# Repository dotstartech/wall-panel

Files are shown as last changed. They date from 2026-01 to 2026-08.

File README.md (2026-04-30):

# Wall Panel

Wall Panel is a 4-inch wall-mounted touch display panel powered by Raspberry Pi Compute Module 4 (CM4). It features a 720x720 IPS multitouch display and can be used as a Home Assistant dashboard or any other embedded display application.

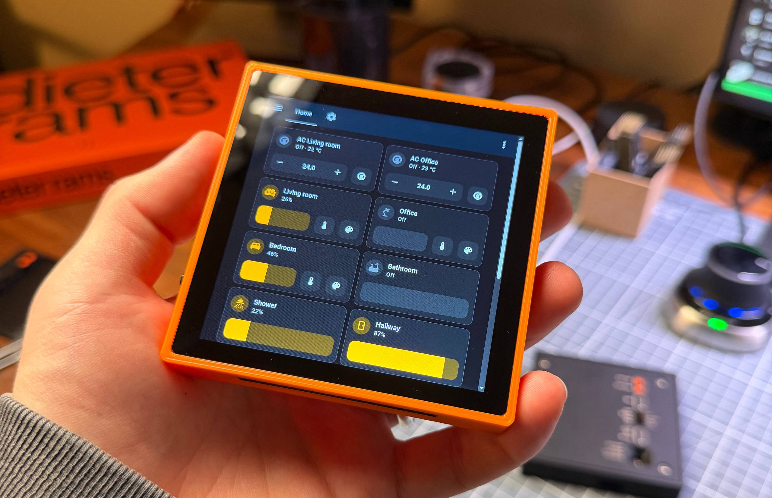
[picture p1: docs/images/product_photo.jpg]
Product photo


## Display
We use this [display](https://www.alibaba.com/product-detail/Square-4-Inch-IPS-LCD-Screen_1601268288719.html), but touch variant. It is 4 lane MIPI with i2c touch controller. 
- Display driver: ST7703
- Touch driver: FT6336U

## Possible use cases
- **Home Assistant Dashboard**. Perfect for wall-mounted smart home control panels with full touch interaction and high-resolution display.
- **Information Display**. Show weather, calendar, news, or any other dynamic content in your home or office.
- **Control Panel**. Use as a centralized control interface for IoT devices, lighting, or home automation systems.
- **Embedded Display**. Build custom applications using the full power of Raspberry Pi OS or any Linux distribution on the CM4.

## List of features
- **720x720 IPS Display** with multitouch support
- **Raspberry Pi Compute Module 4** as the main brain
- **External RTC** for accurate timekeeping
- **USB-C** for data and power
- **USB-OTG** support for device mode
- **Action Button** for user interaction
- **WiFi** connectivity
- **40-pin GPIO Header** for Raspberry Pi compatibility
- **SD Card** slot for storage expansion
- **Micro HDMI** output for external displays
- **EEPROM Flashing** capability for firmware updates
- **Backplane Connector** for power and data from the wall and future PoE backplate support

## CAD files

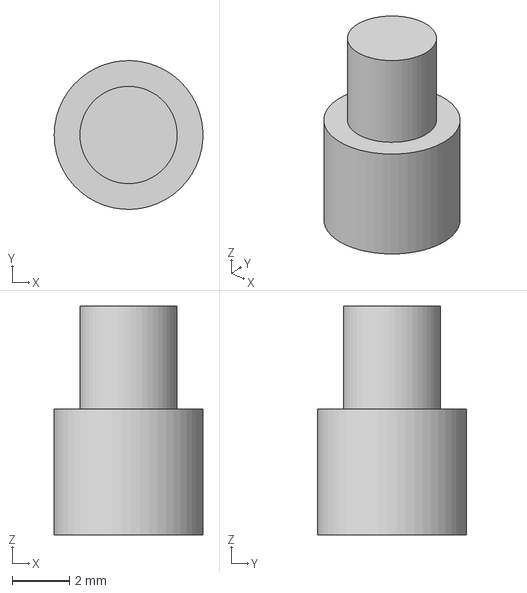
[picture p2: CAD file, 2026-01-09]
cad/wall-panel/back_button.step
5.20 x 5.20 x 8.00 mm

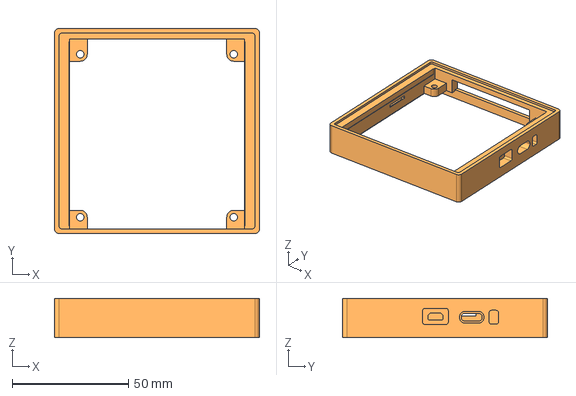
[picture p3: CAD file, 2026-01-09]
cad/wall-panel/frame.step
88.2 x 88.2 x 16.8 mm

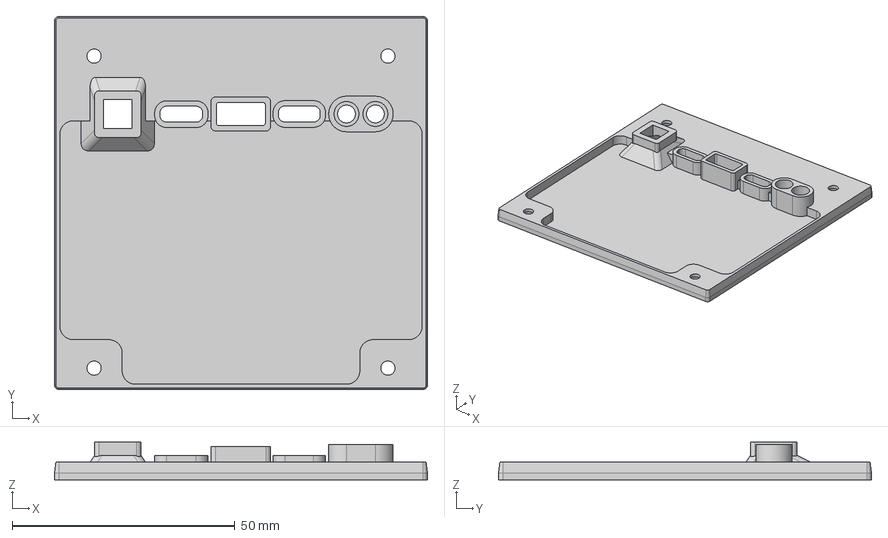
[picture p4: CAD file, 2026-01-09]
cad/wall-panel/back_lid.step
83.8 x 83.8 x 8.50 mm

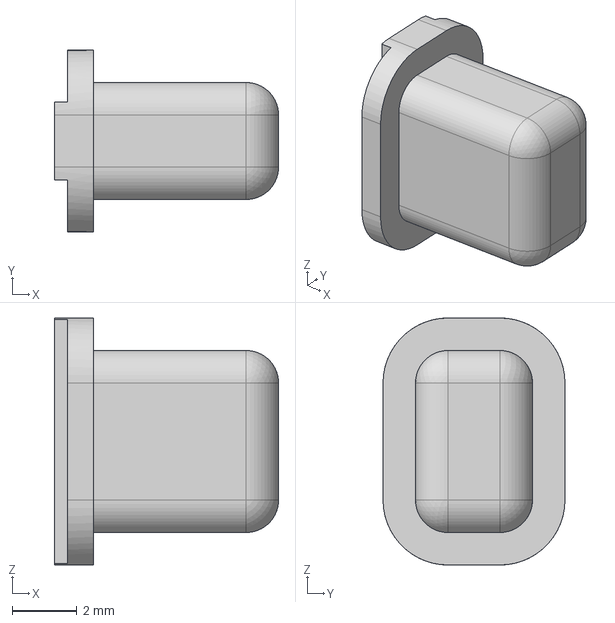
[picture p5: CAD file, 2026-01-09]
cad/wall-panel/side_button.step
6.90 x 5.60 x 7.60 mm

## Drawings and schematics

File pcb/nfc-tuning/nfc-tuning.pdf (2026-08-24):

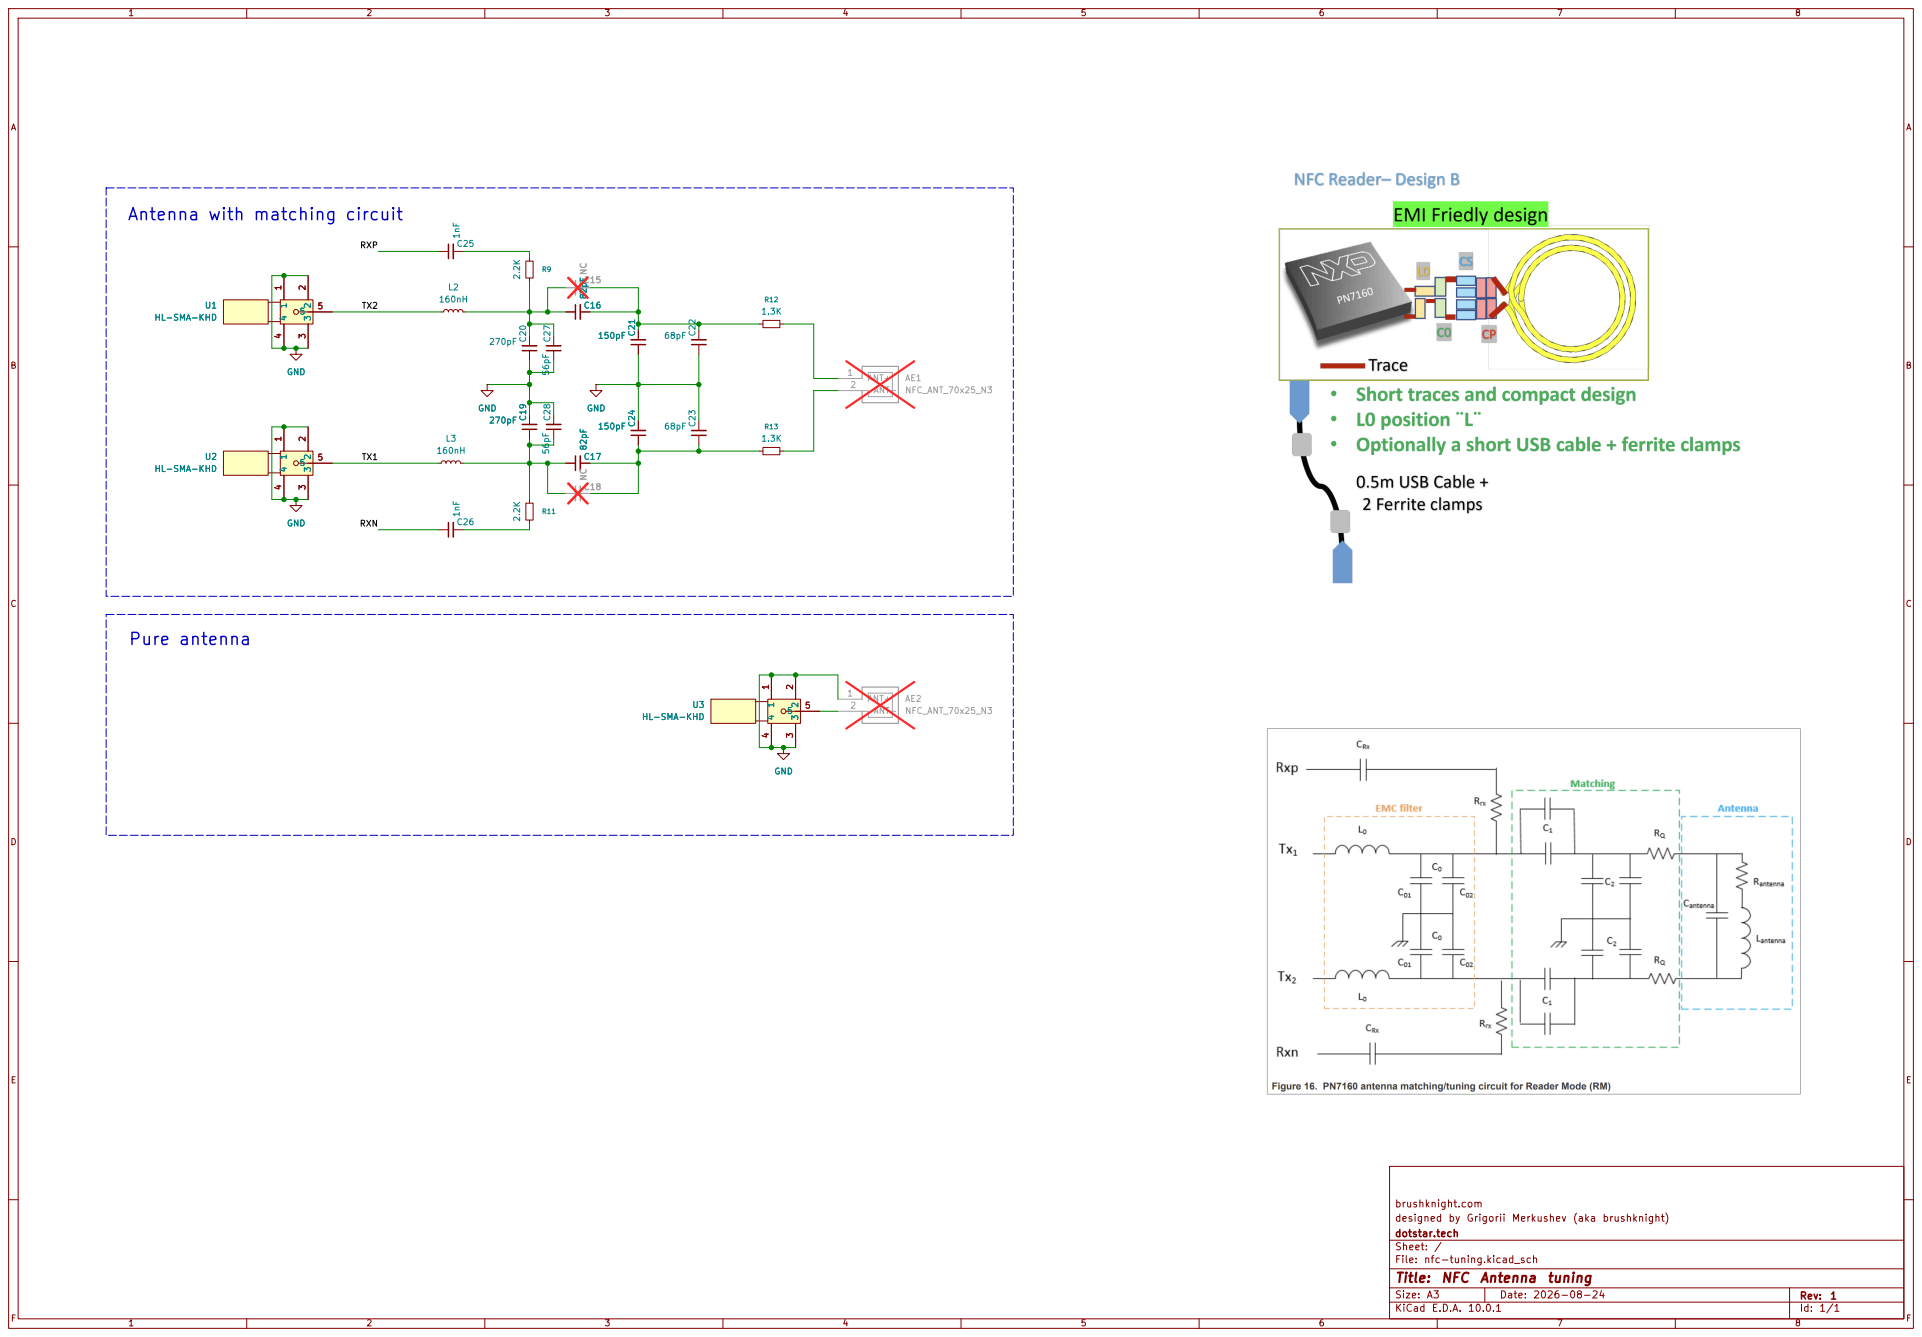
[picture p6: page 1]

Antenna with matching circuit

GND U1 HL-SMA-KHD

designed by Grigorii Merkushev (aka brushknight)
dotstar.tech
Sheet: /
File: nfc-tuning.kicad_sch
Title: NFC Antenna tuning

Size: A3 | Rev: 1 | F Date: 2026-08-24
KiCad E.D.A. 10.0.1 | Id: 1/1

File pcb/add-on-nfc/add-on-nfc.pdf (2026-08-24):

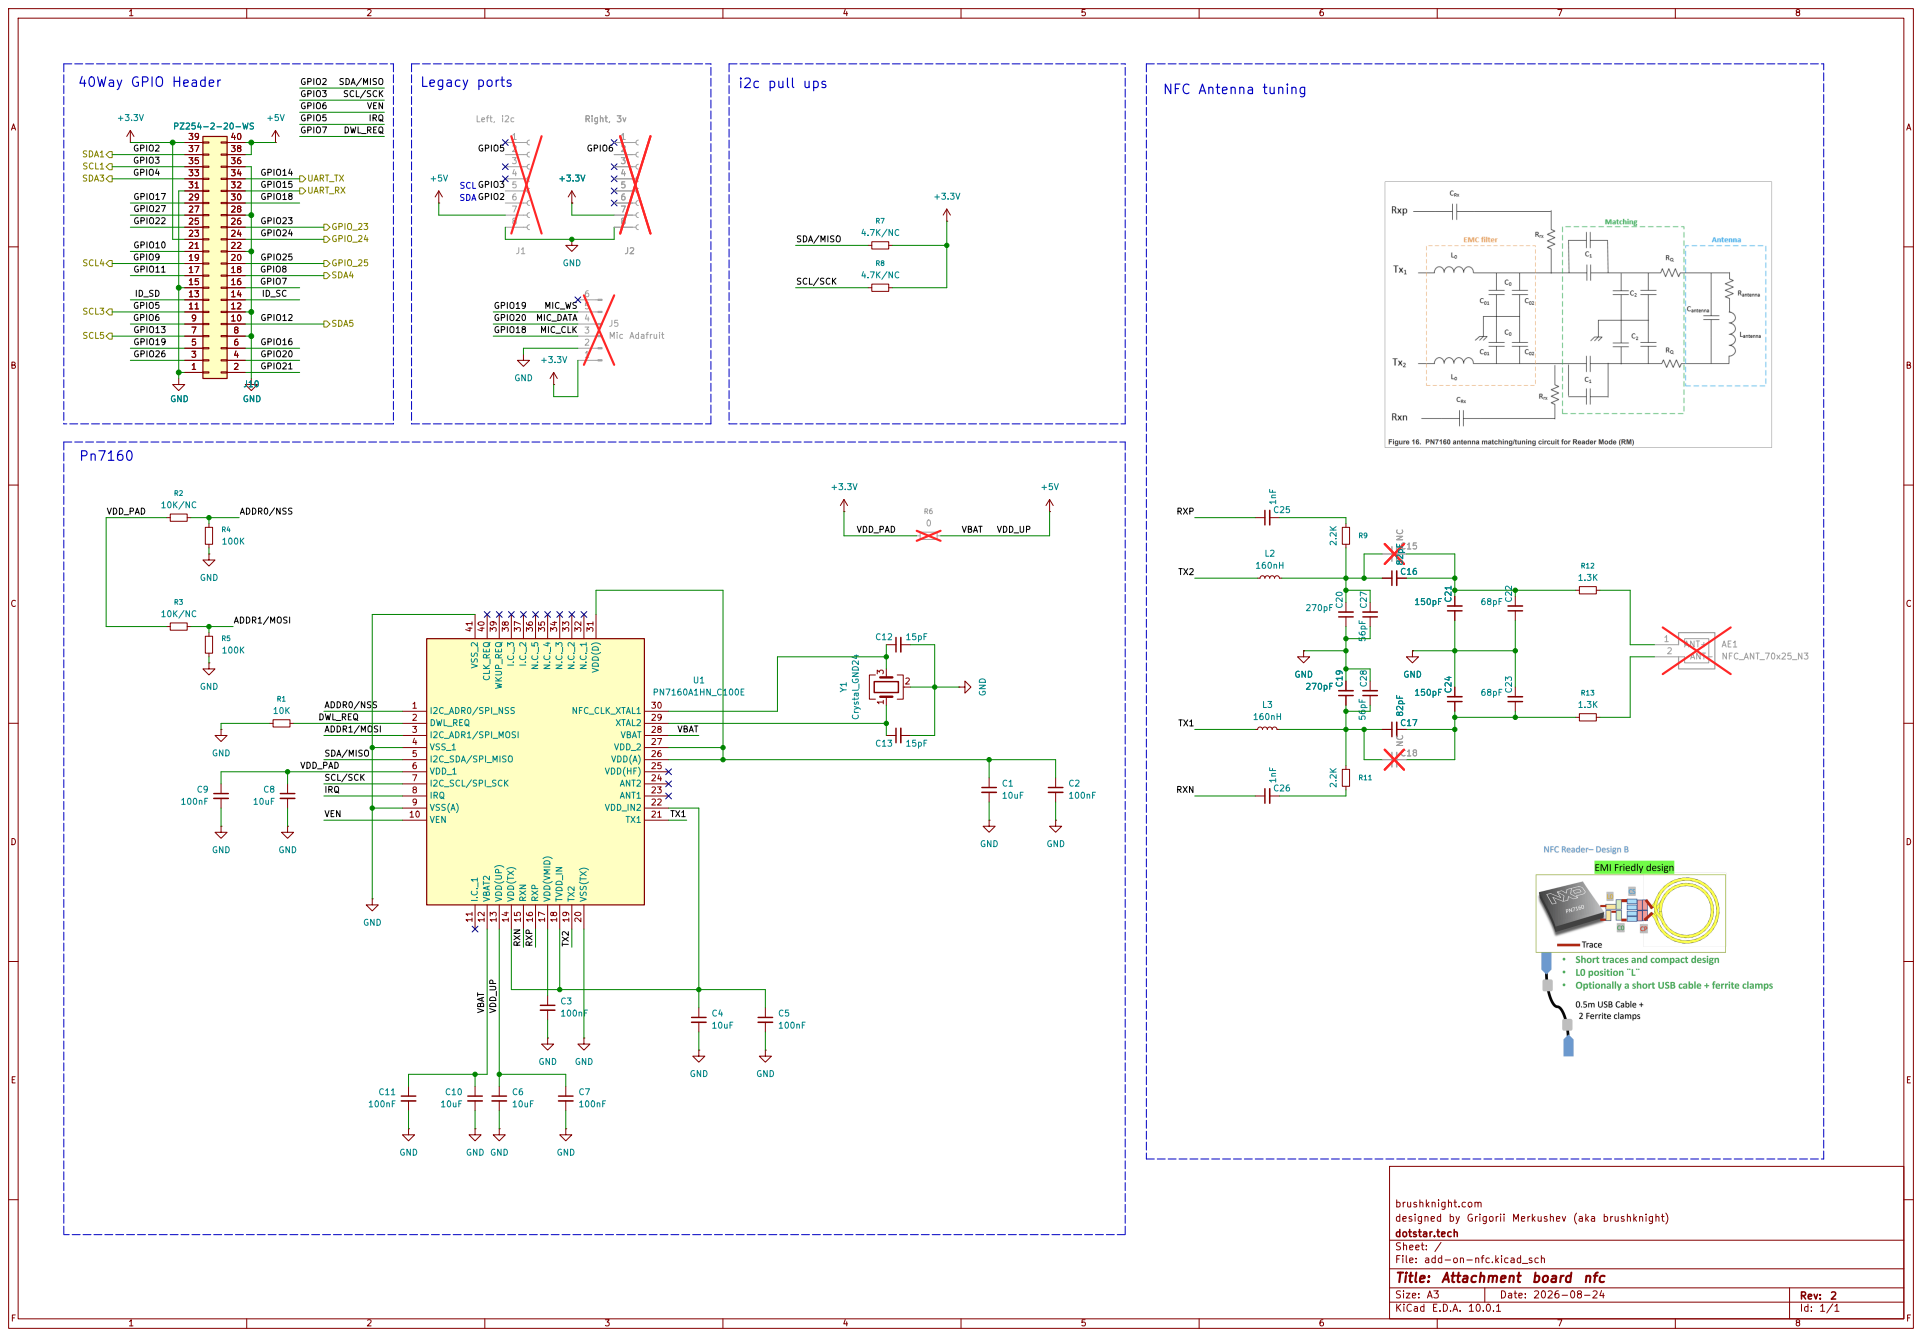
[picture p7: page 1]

brushknight.com
designed by Grigorii Merkushev (aka brushknight)
dotstar.tech
Sheet: /
File: add-on-nfc.kicad_sch
Title: Attachment board nfc

Size: A3 | Rev: 2 | F Date: 2026-08-24
KiCad E.D.A. 10.0.1 | Id: 1/1

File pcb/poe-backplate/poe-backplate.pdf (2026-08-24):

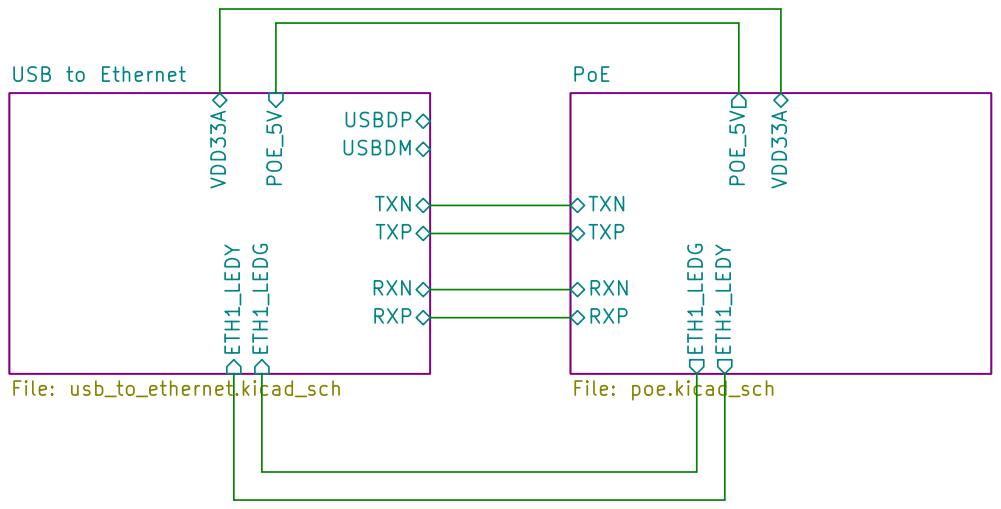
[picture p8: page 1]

brushknight.com
designed byGrigorii Merkushev (aka brushknight)
dotstar.tech
Sheet: /
File: poe-backplate.kicad_sch
Title: PoE Backplate

Size: A3 | Rev: 4 | F Date: 2026-08-05
KiCad E.D.A. 10.0.1 | Id: 1/3

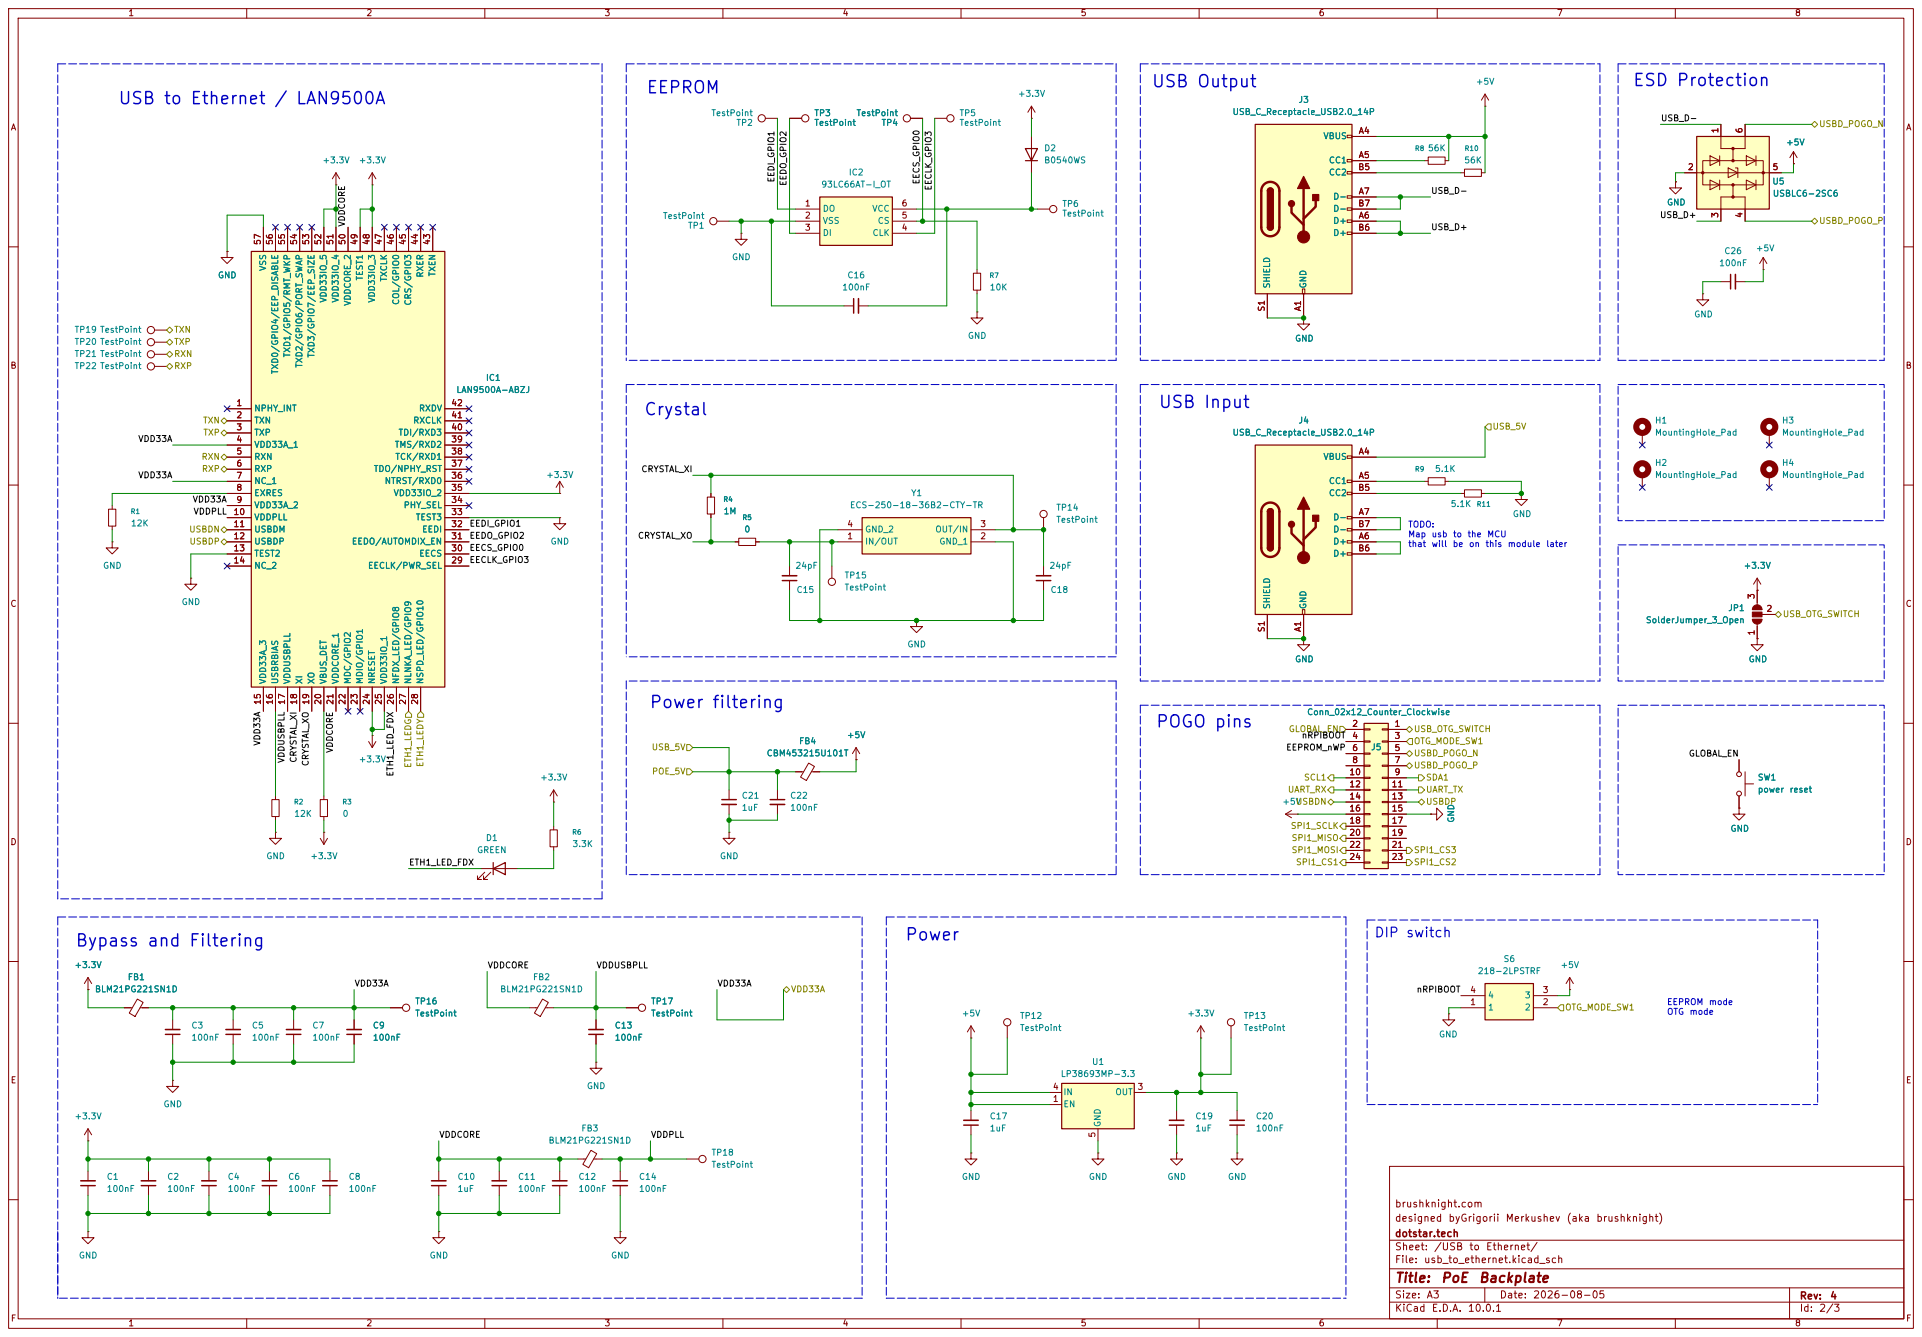
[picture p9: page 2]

USB Output USB to Ethernet / LAN9500A
TestPoint +3.3V

TODO: Map usb to the MCU

EEPROM mode OTG mode

brushknight.com
designed byGrigorii Merkushev (aka brushknight)
dotstar.tech
Sheet: /USB to Ethernet/
File: usb_to_ethernet.kicad_sch

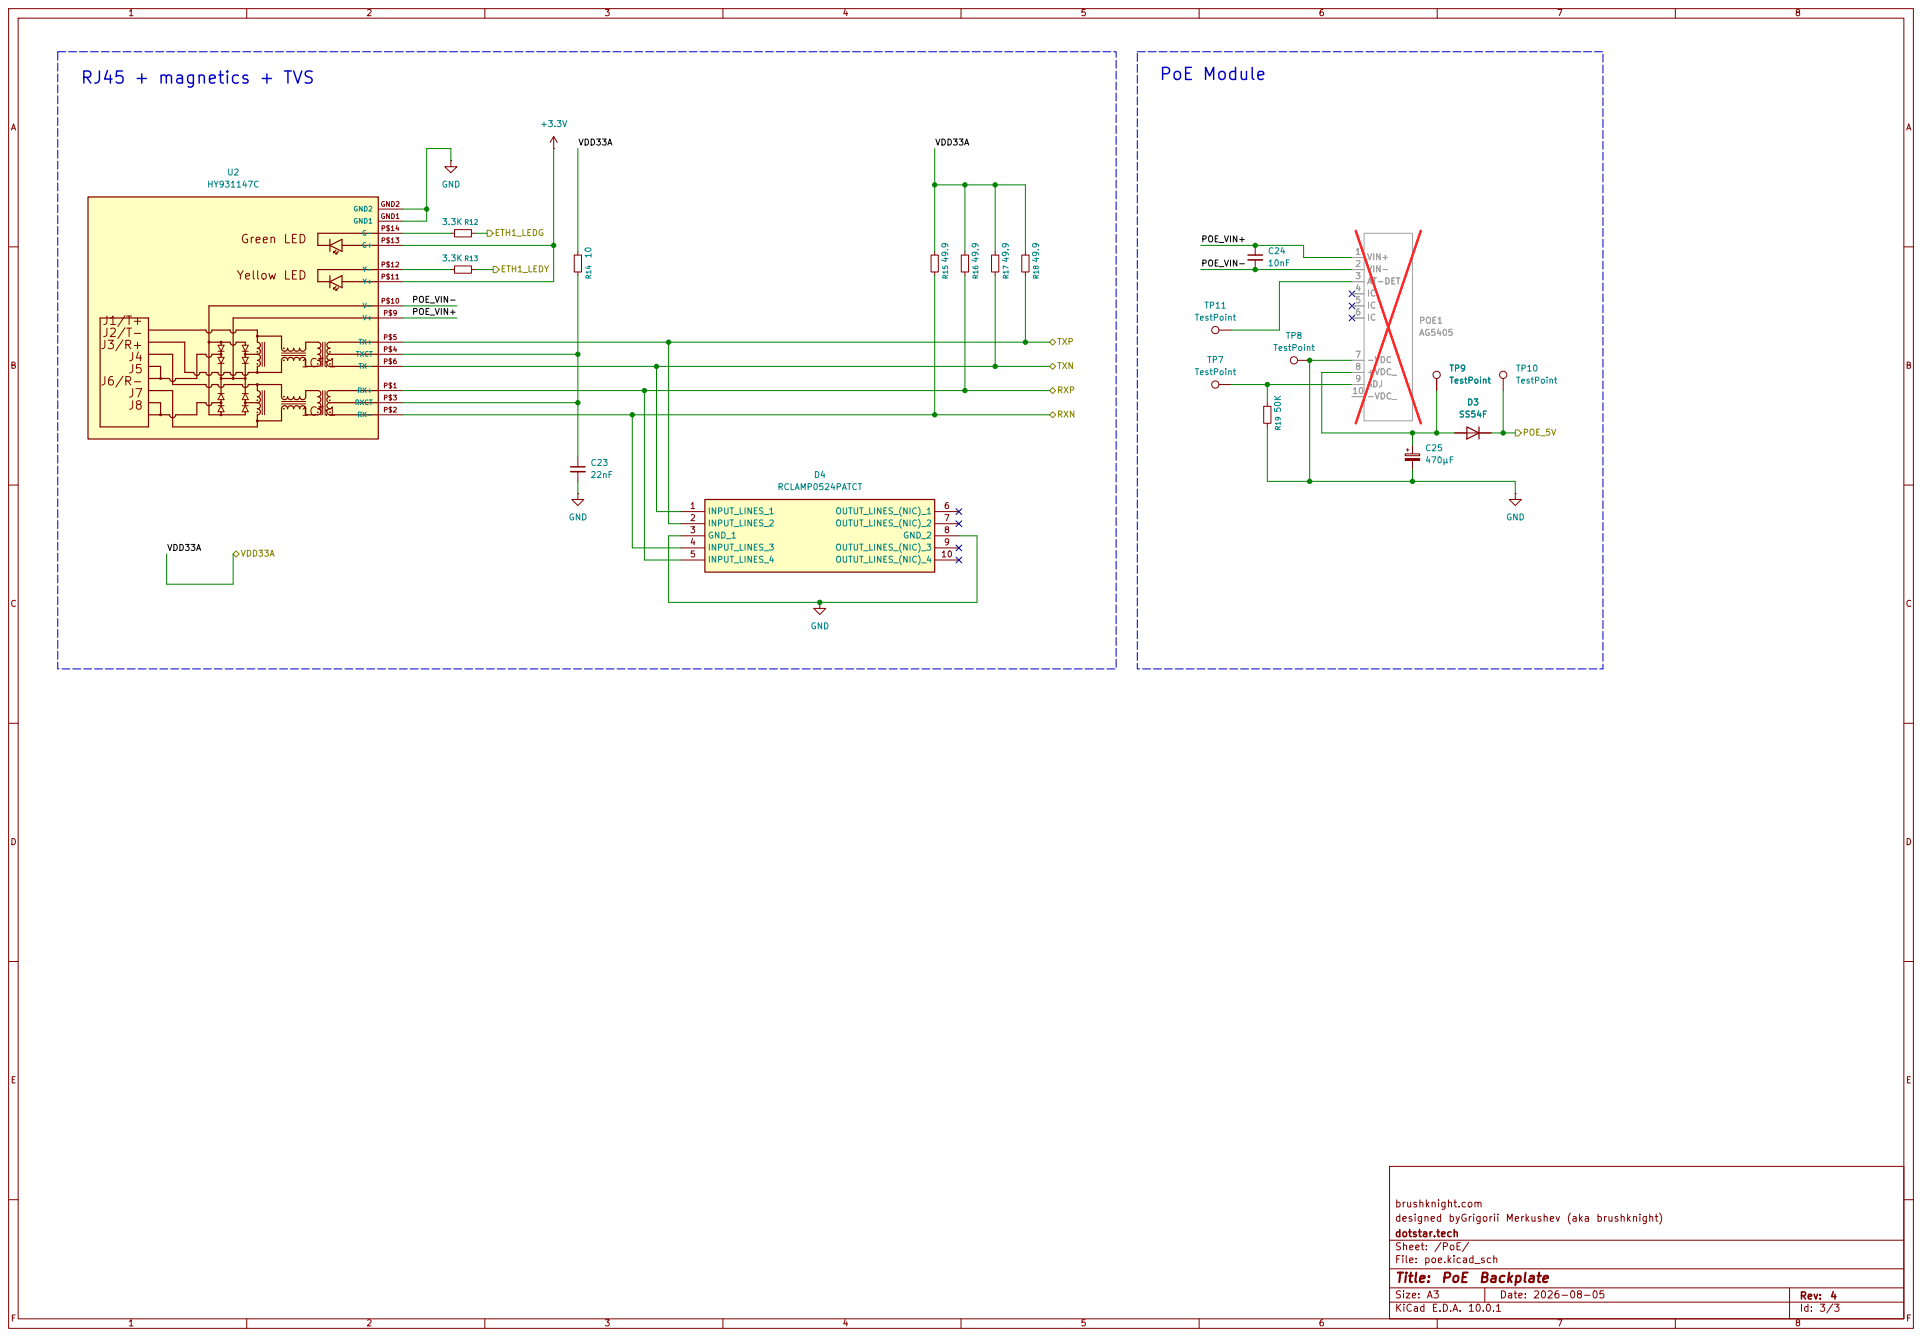
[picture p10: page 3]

brushknight.com
designed byGrigorii Merkushev (aka brushknight)
dotstar.tech
Sheet: /PoE/
File: poe.kicad_sch

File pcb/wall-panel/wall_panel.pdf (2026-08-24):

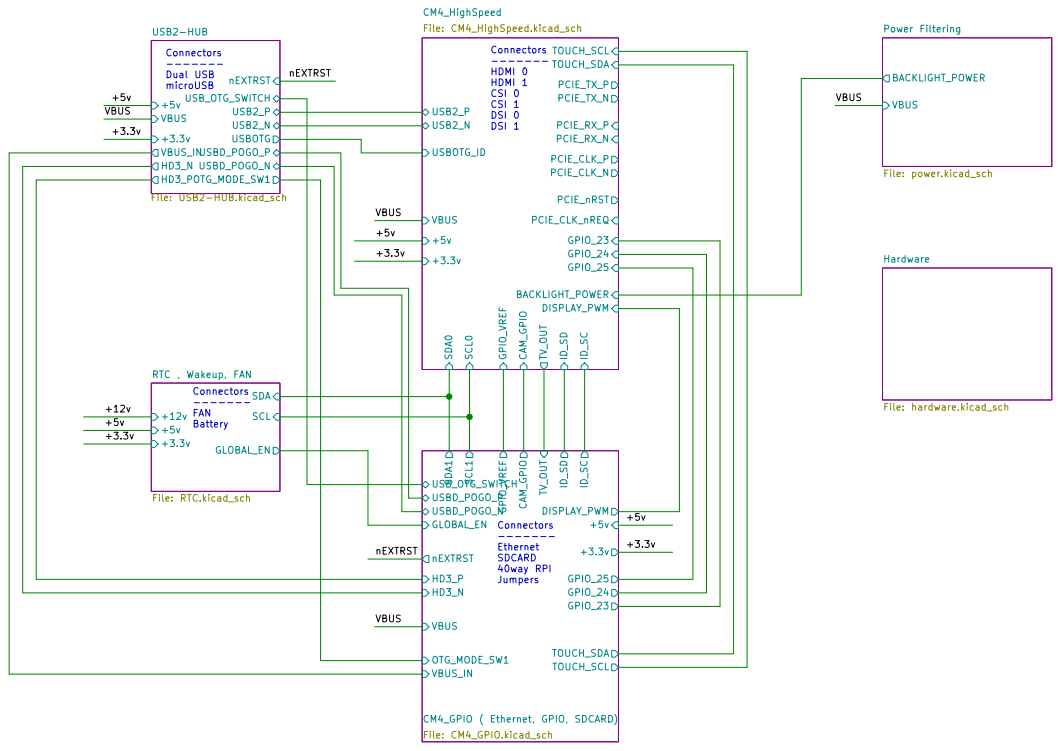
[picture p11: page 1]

TOUCH_SDA BACKLIGHT_POWER
HDMI 0 HDMI 1 CSI 0 CSI 1 DSI 0 DSI 1

CM4_GPIO ( Ethernet, GPIO, SDCARD) File: CM4_GPIO.kicad_sch

brushknight.com
designed by Grigorii Merkushev (aka brushknight)
dotstar.tech
Sheet: /
File: wall_panel.kicad_sch
Title: Wall Panel

Size: A3 | Rev: 5 | F Date: 2026-08-24
KiCad E.D.A. 10.0.1 | Id: 1/7

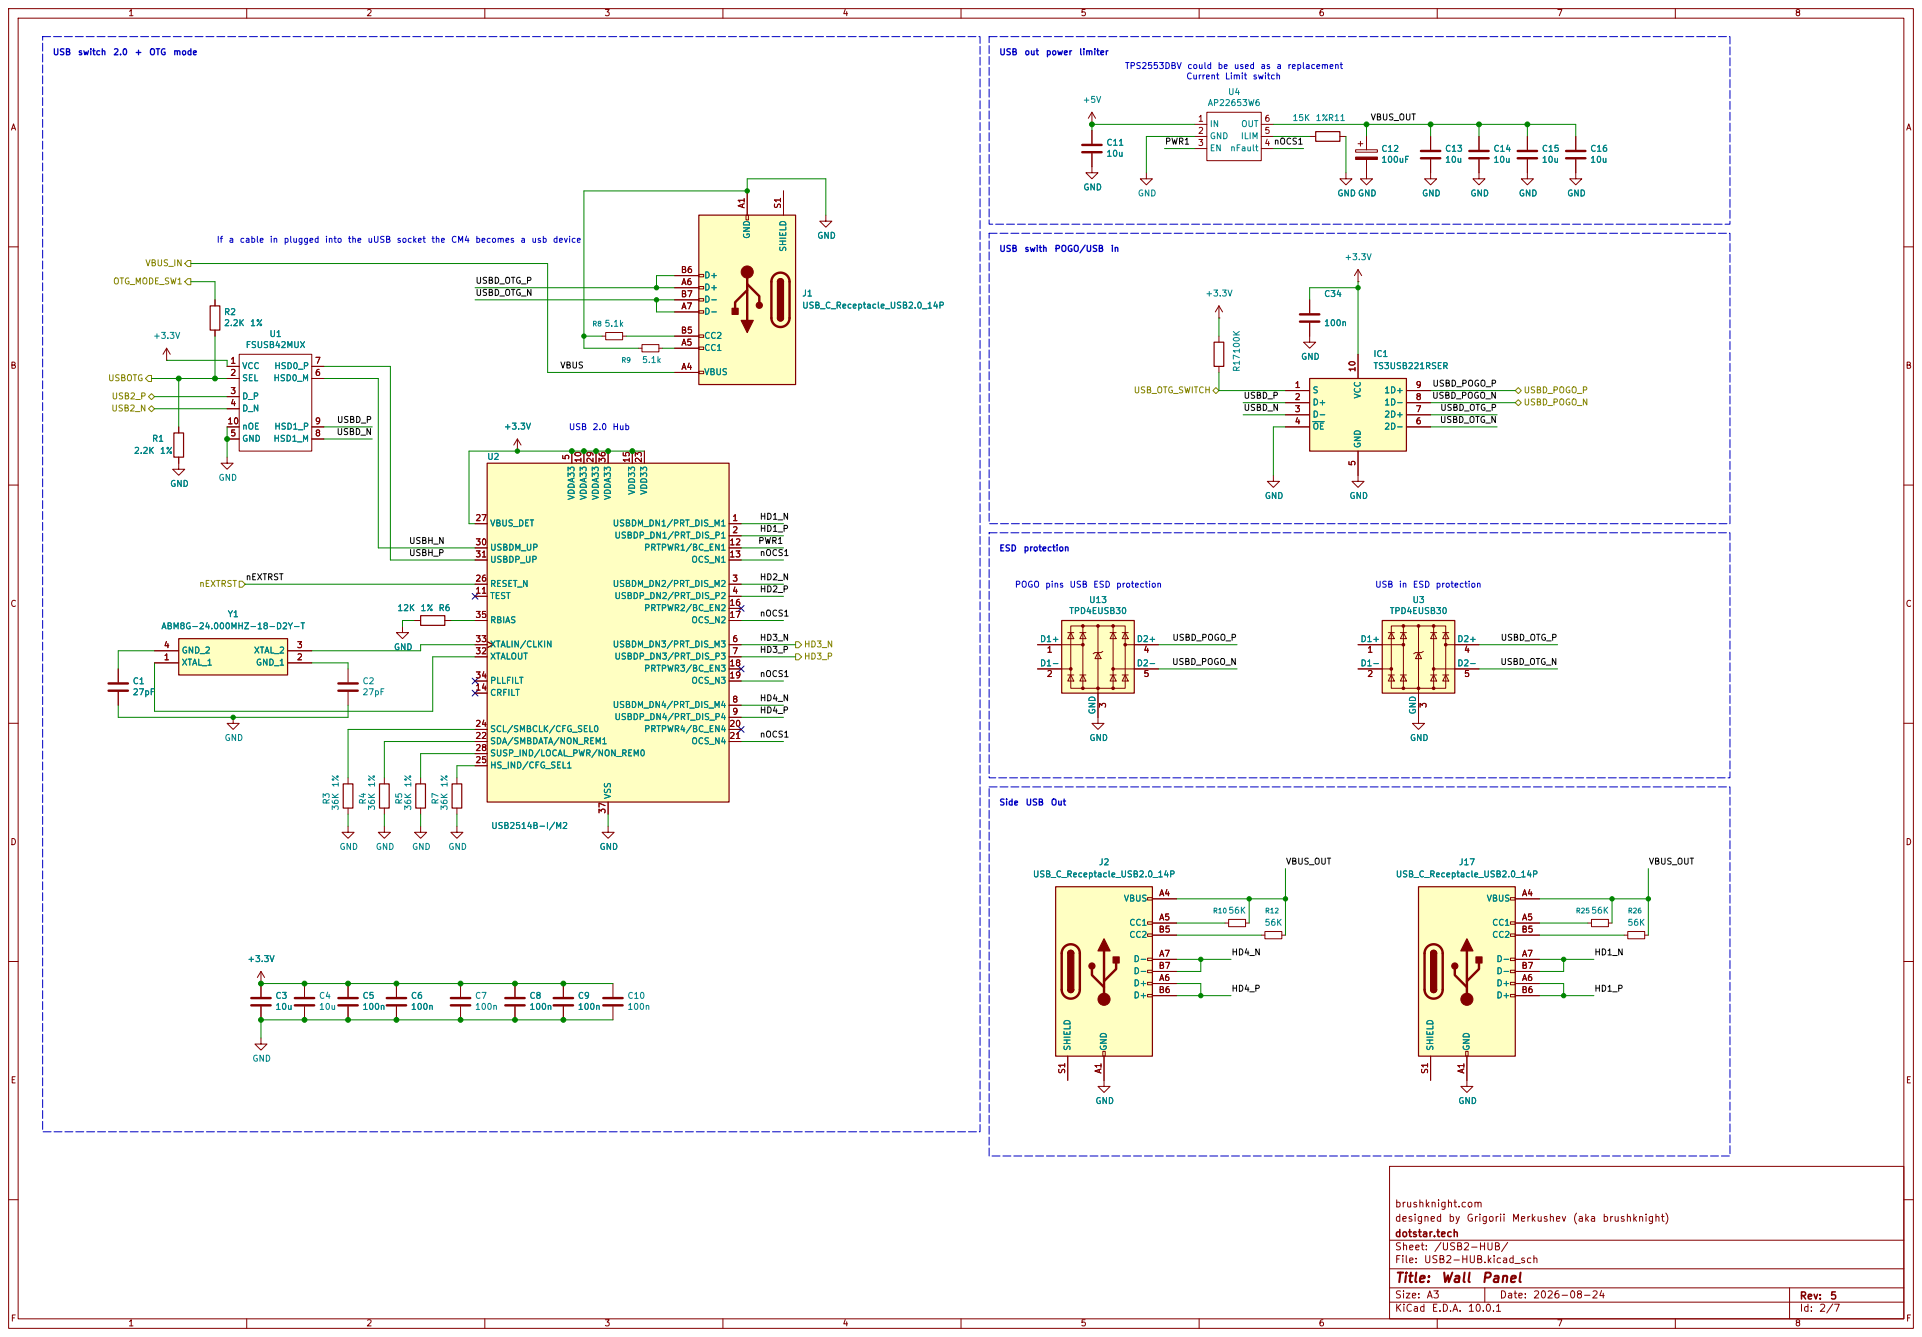
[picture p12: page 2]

brushknight.com
designed by Grigorii Merkushev (aka brushknight)
dotstar.tech
Sheet: /USB2-HUB/
File: USB2-HUB.kicad_sch

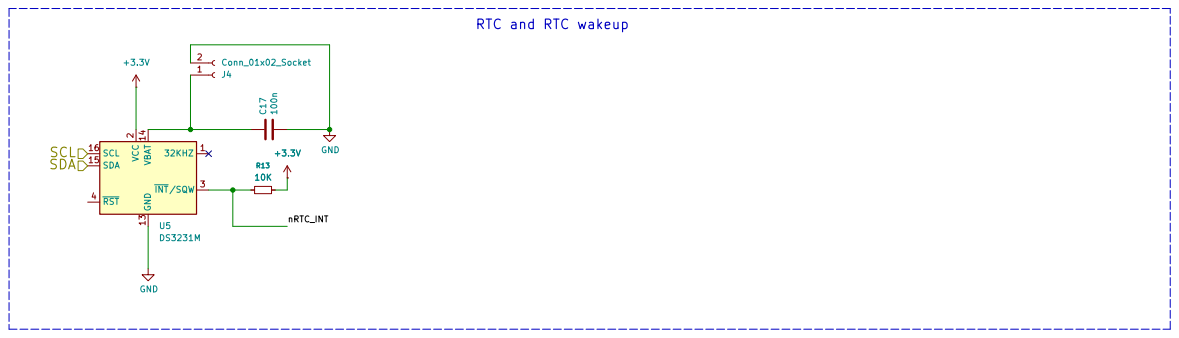
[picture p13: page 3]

brushknight.com
designed by Grigorii Merkushev (aka brushknight)
dotstar.tech
Sheet: /RTC , Wakeup, FAN/
File: RTC.kicad_sch

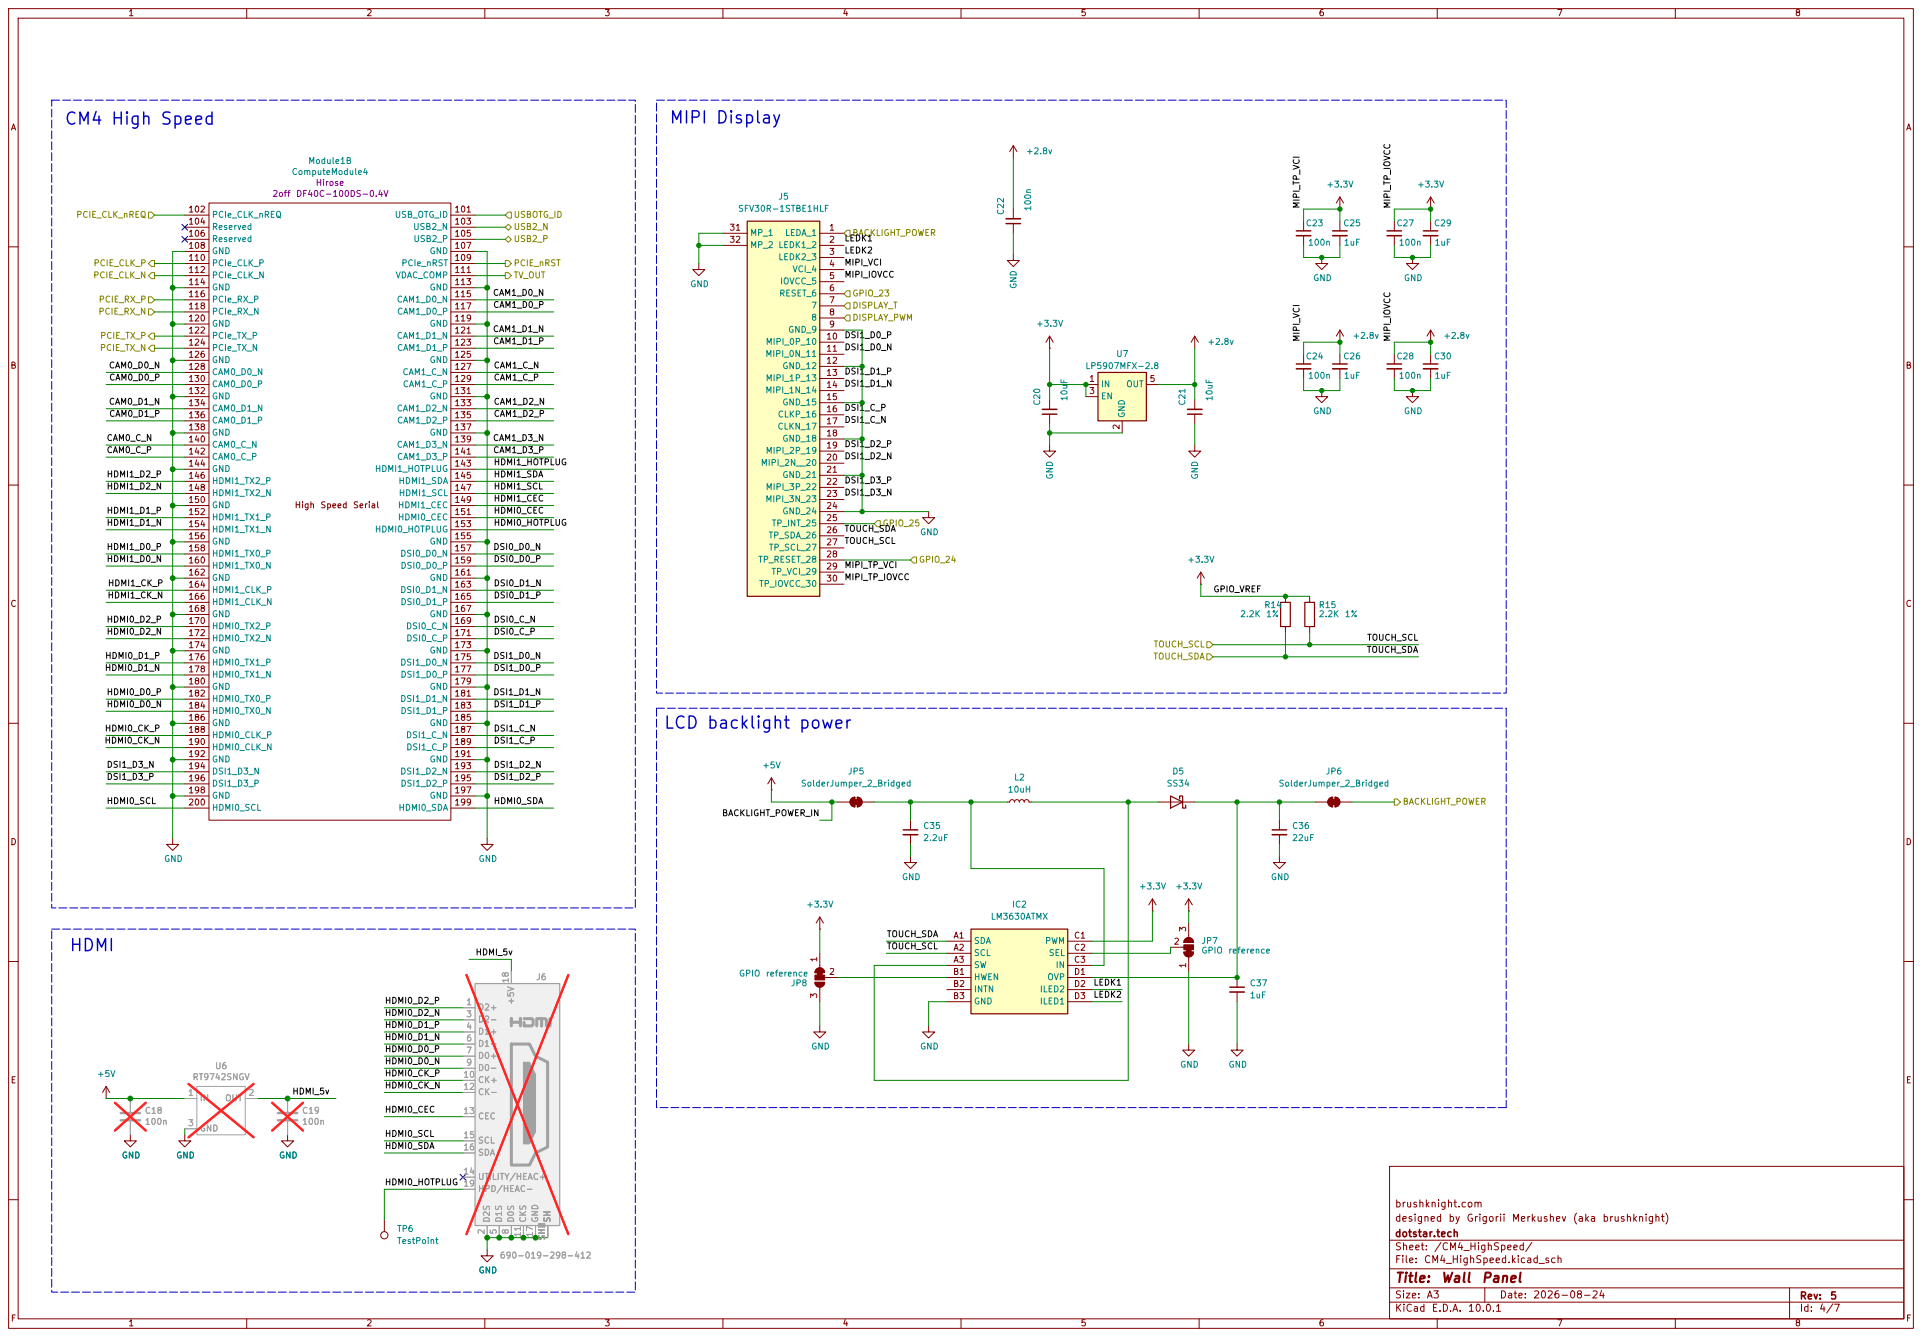
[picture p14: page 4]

8 D0- 9 CK+ 10 CKS 11 CK- 12 CEC 13 UTILITY/HEAC+ 14

brushknight.com
designed by Grigorii Merkushev (aka brushknight)
dotstar.tech
Sheet: /CM4_HighSpeed/
File: CM4_HighSpeed.kicad_sch

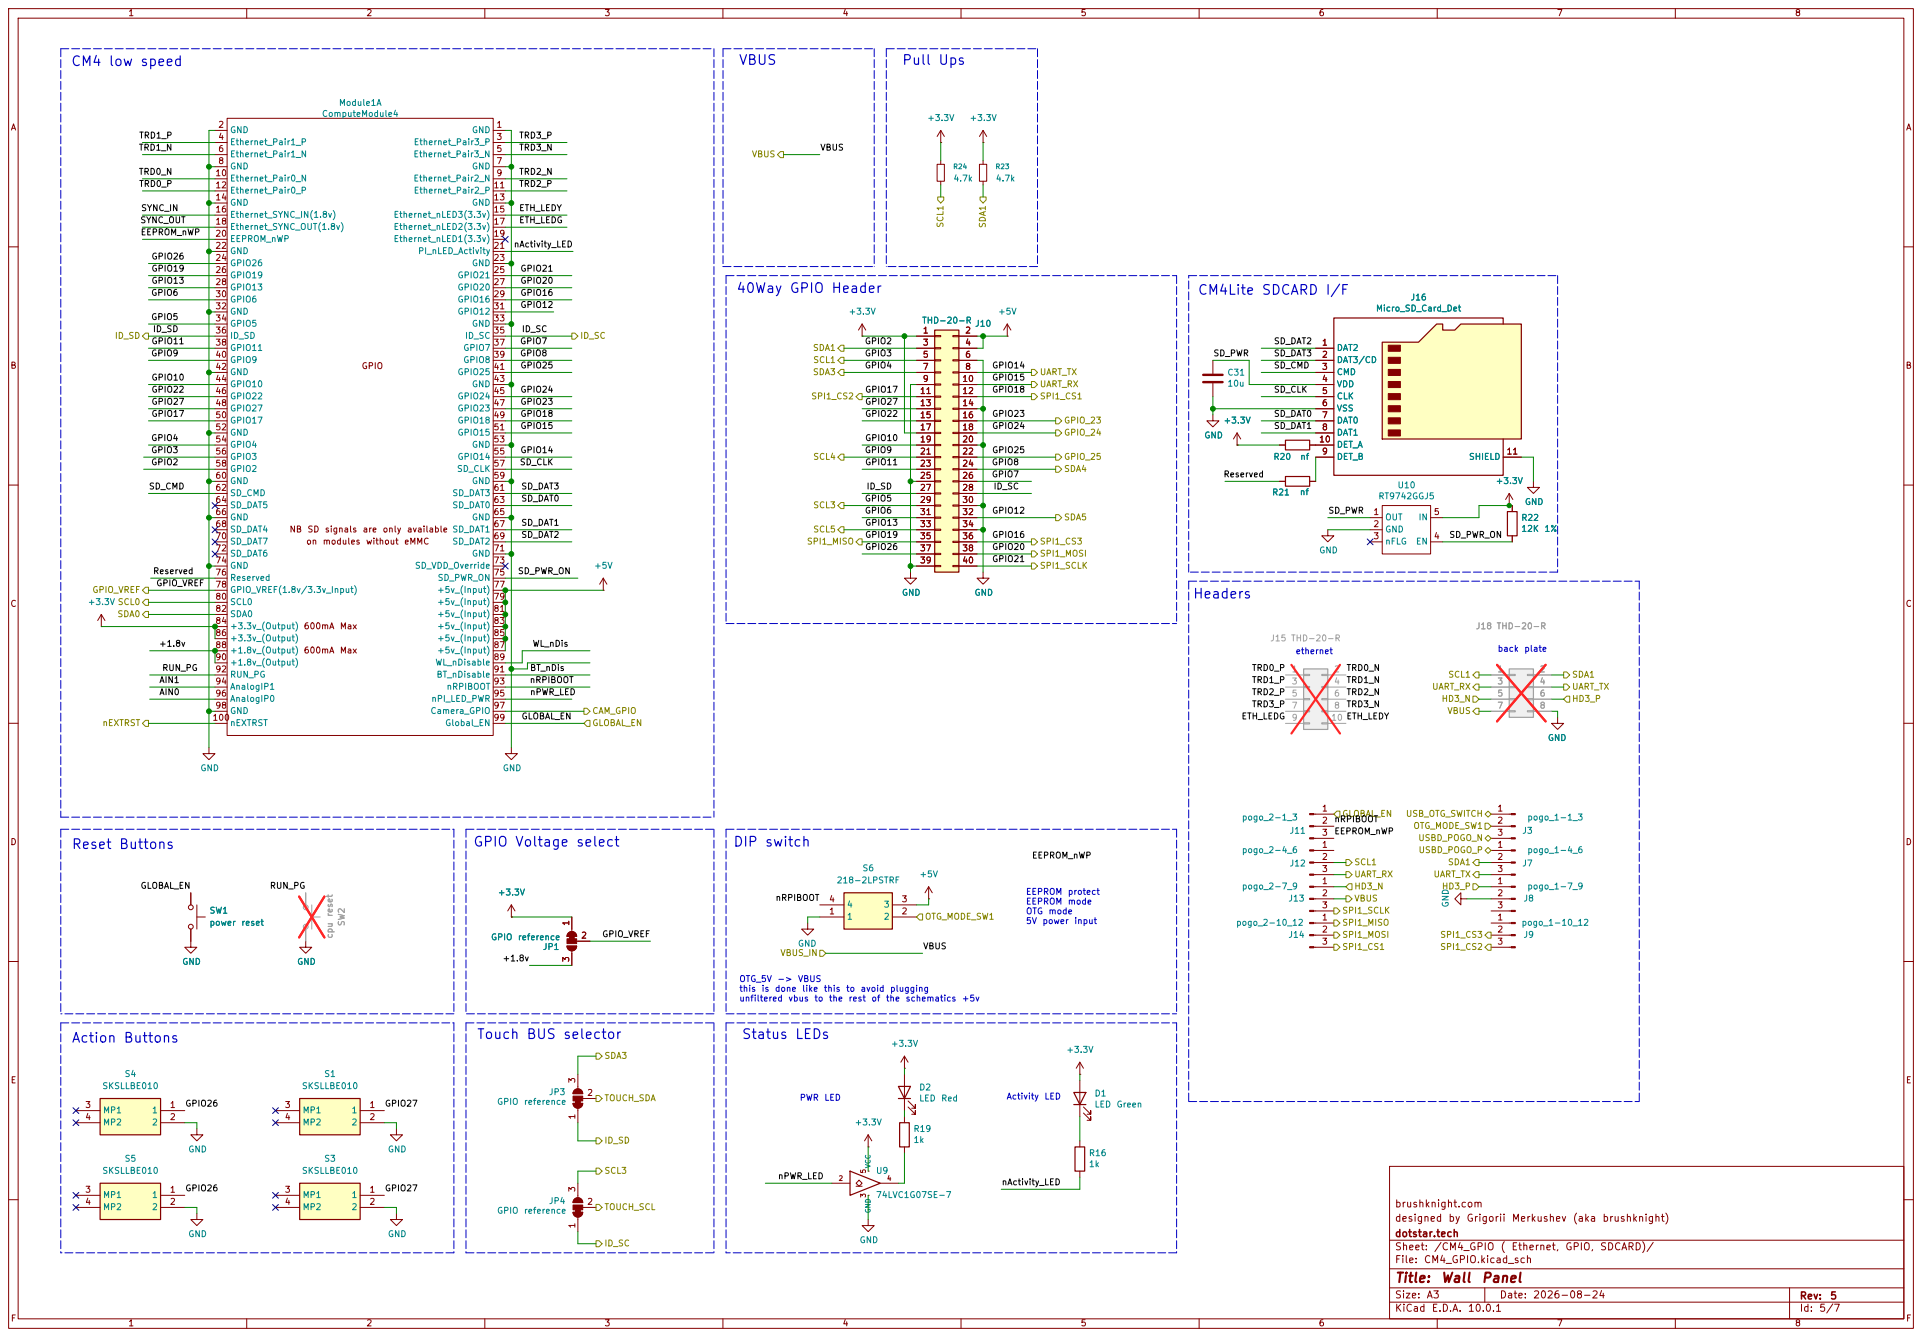
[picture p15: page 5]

600mA Max 600mA Max NB SD signals are only available on modules without eMMC

EEPROM protect EEPROM mode OTG mode 5V power input

Activity LED OTG_5V -> VBUS
this is done like this to avoid plugging
unfiltered vbus to the rest of the schematics +5v

brushknight.com
designed by Grigorii Merkushev (aka brushknight)
dotstar.tech
Sheet: /CM4_GPIO ( Ethernet, GPIO, SDCARD)/
File: CM4_GPIO.kicad_sch

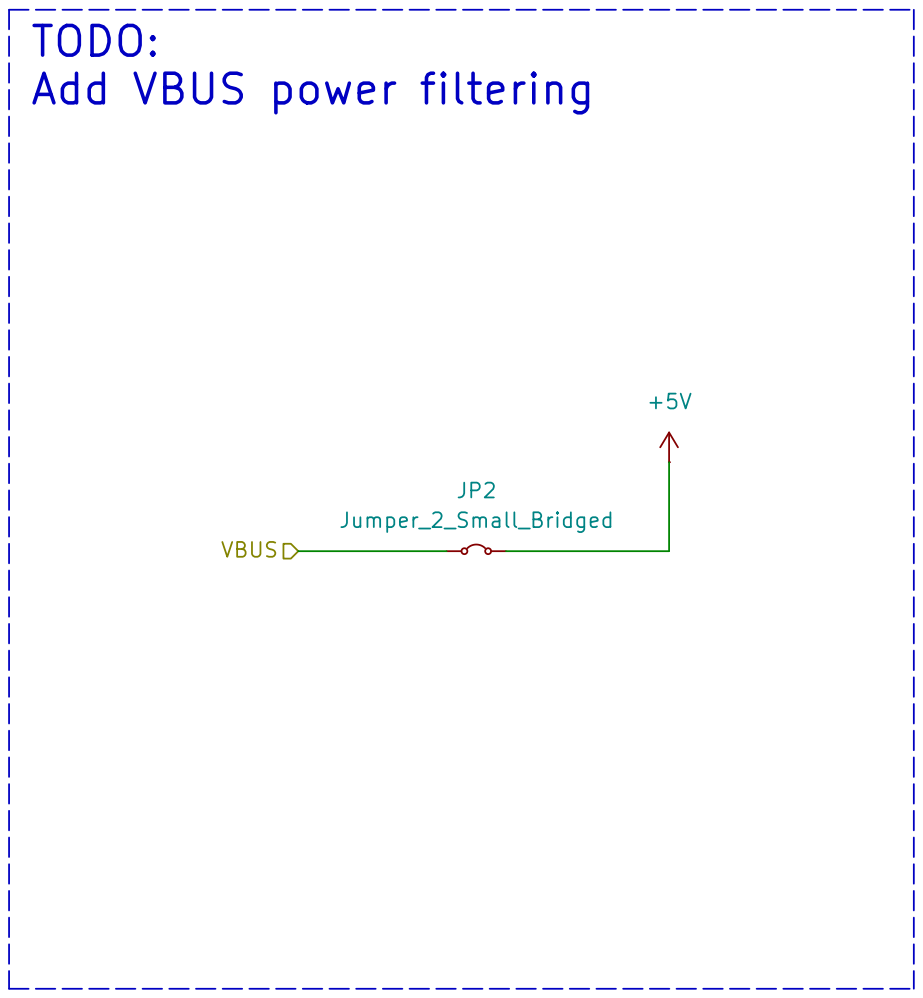
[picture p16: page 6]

VBUS TODO:
Add VBUS power filtering

brushknight.com
designed by Grigorii Merkushev (aka brushknight)
dotstar.tech
Sheet: /Power Filtering/
File: power.kicad_sch

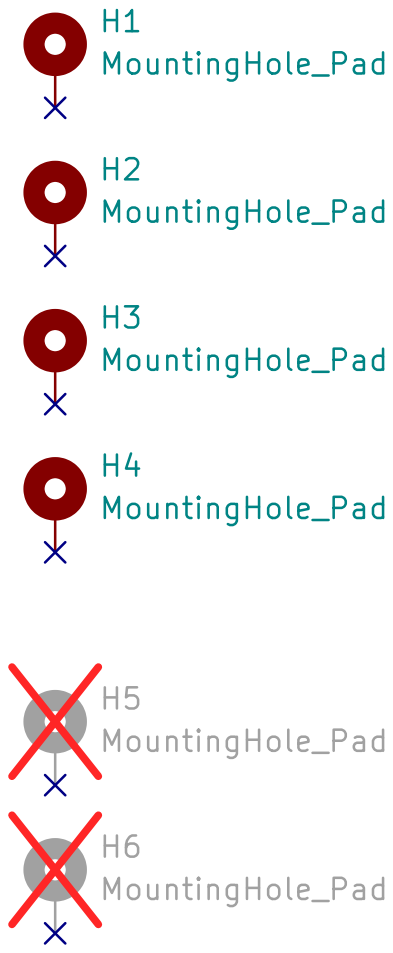
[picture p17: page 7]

brushknight.com
designed by Grigorii Merkushev (aka brushknight)
dotstar.tech
Sheet: /Hardware/
File: hardware.kicad_sch

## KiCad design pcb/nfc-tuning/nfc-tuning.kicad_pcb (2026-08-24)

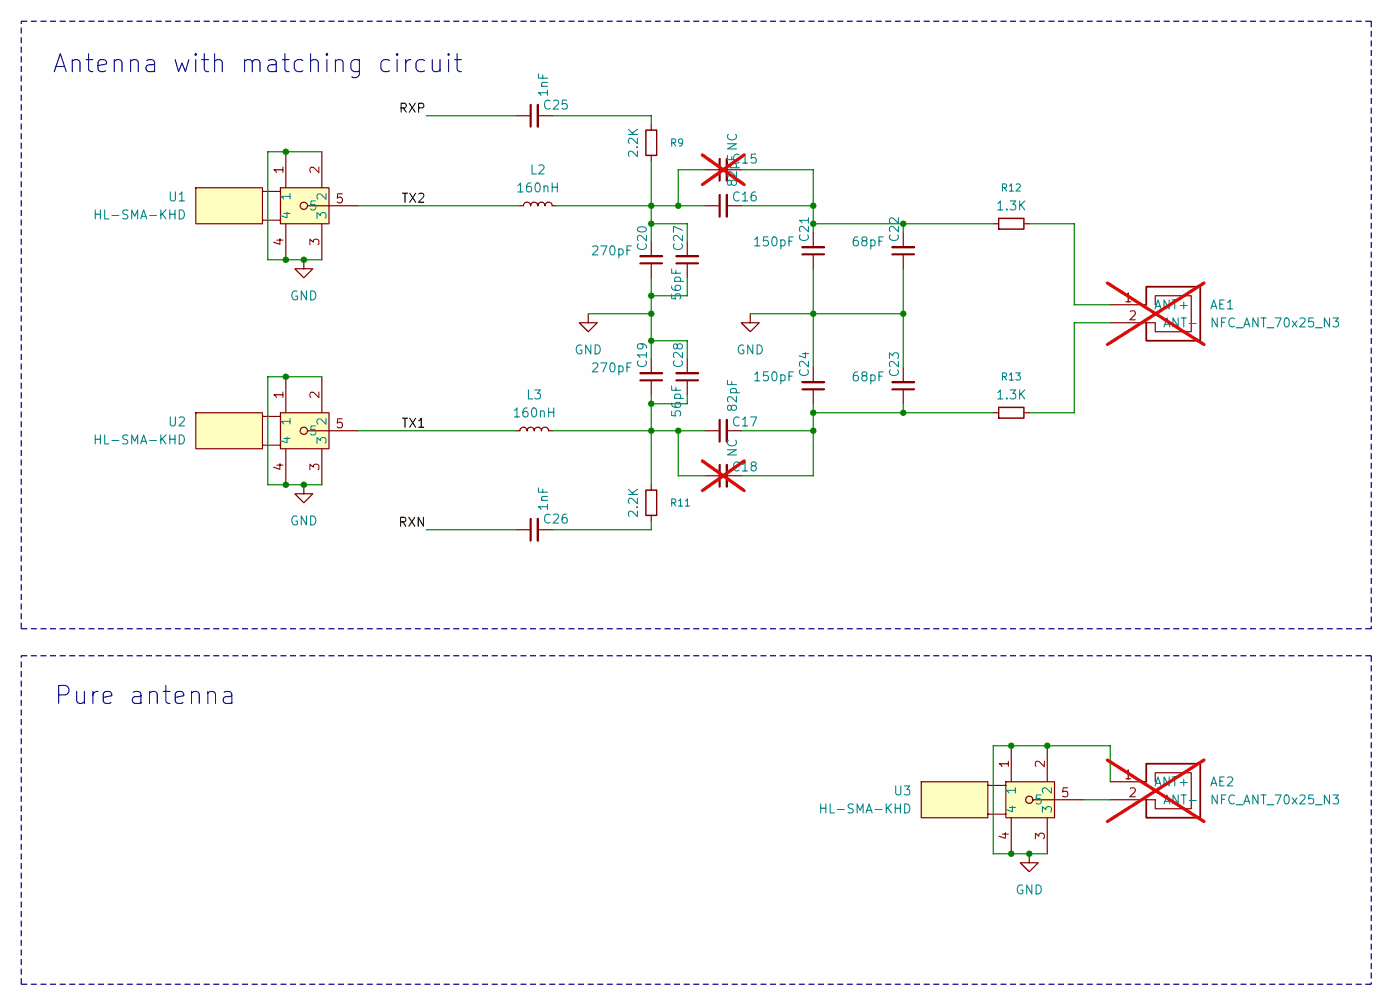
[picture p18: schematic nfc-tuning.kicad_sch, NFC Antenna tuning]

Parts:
AE1, AE2: NFC_ANT_70x25_N3; not fitted
C15, C18: NC; C_0402_1005Metric; not fitted
C16, C17: 82pF; C_0402_1005Metric; LCSC C162123
C19, C20: 270pF; C_0402_1005Metric; LCSC C882580
C21, C24: 150pF; C_0402_1005Metric; LCSC C237333
C22, C23: 68pF; C_0402_1005Metric; LCSC C2987942
C25, C26: 1nF; C_0402_1005Metric; LCSC C161523
C27, C28: 56pF; C_0402_1005Metric; LCSC C2189899
L2, L3: 160nH; L_0603_1608Metric; LCSC C437367
R9, R11: 2.2K; R_0402_1005Metric; LCSC C2906865
R12, R13: 1.3K; R_0402_1005Metric; LCSC C185455
U1, U2, U3: HL-SMA-KHD; SMA-TH_HL-SMA-KHD2; MPN HL-SMA-KHD; LCSC Part C19712120

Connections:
/RXN: C26.1
/RXP: C25.1
/TX1: L3.1, U2.5
/TX2: L2.1, U1.5
GND: AE2.1 (ANT+), AE2.2 (ANT-), C19.2, C20.1, C21.1, C22.1, C23.2, C24.2, C27.1, C28.2, U1.1, U1.2, U1.3, U1.4, U2.1, U2.2, U2.3, U2.4, U3.1, U3.2, U3.3, U3.4; also elsewhere on the board
unnamed: AE1.1 (ANT+), R12.2
unnamed: AE1.2 (ANT-), R13.2
unnamed: AE2.2 (ANT-), U3.5
unnamed: C15.1, C16.1, C20.2, C27.2, L2.2, R9.1
unnamed: C15.2, C16.2, C21.2, C22.2, R12.1
unnamed: C17.1, C18.1, C19.1, C28.1, L3.2, R11.2
unnamed: C17.2, C18.2, C23.1, C24.1, R13.1
unnamed: C25.2, R9.2
unnamed: C26.2, R11.1

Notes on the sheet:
Antenna with matching circuit
Pure antenna

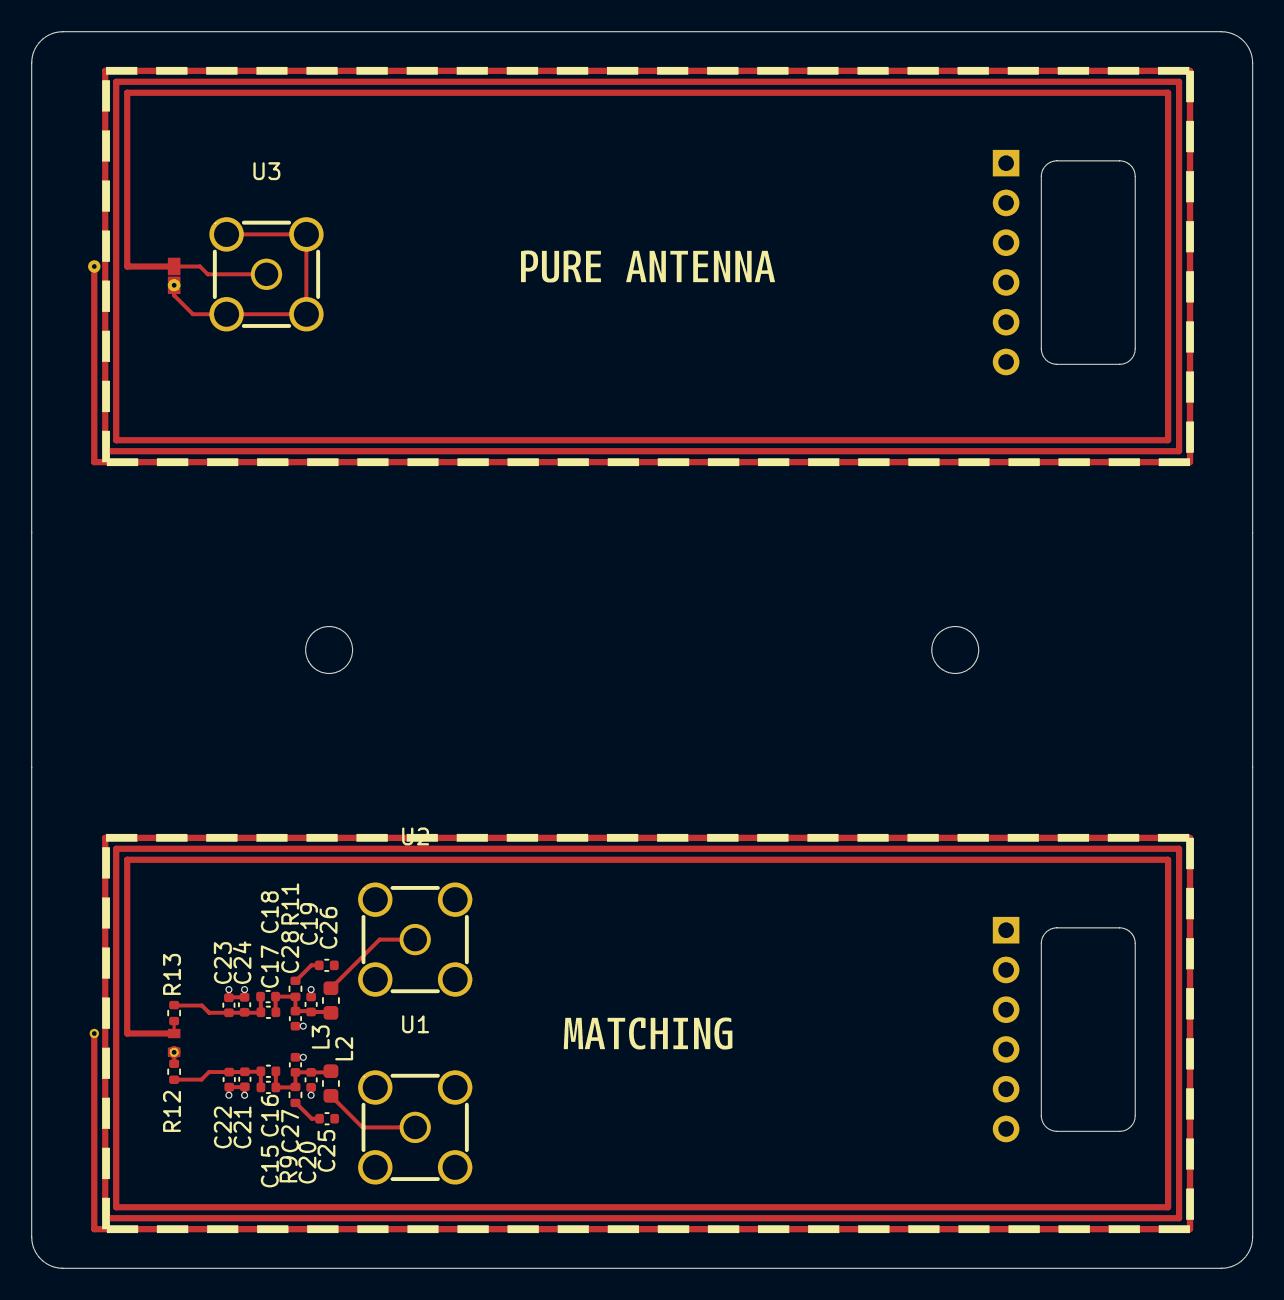
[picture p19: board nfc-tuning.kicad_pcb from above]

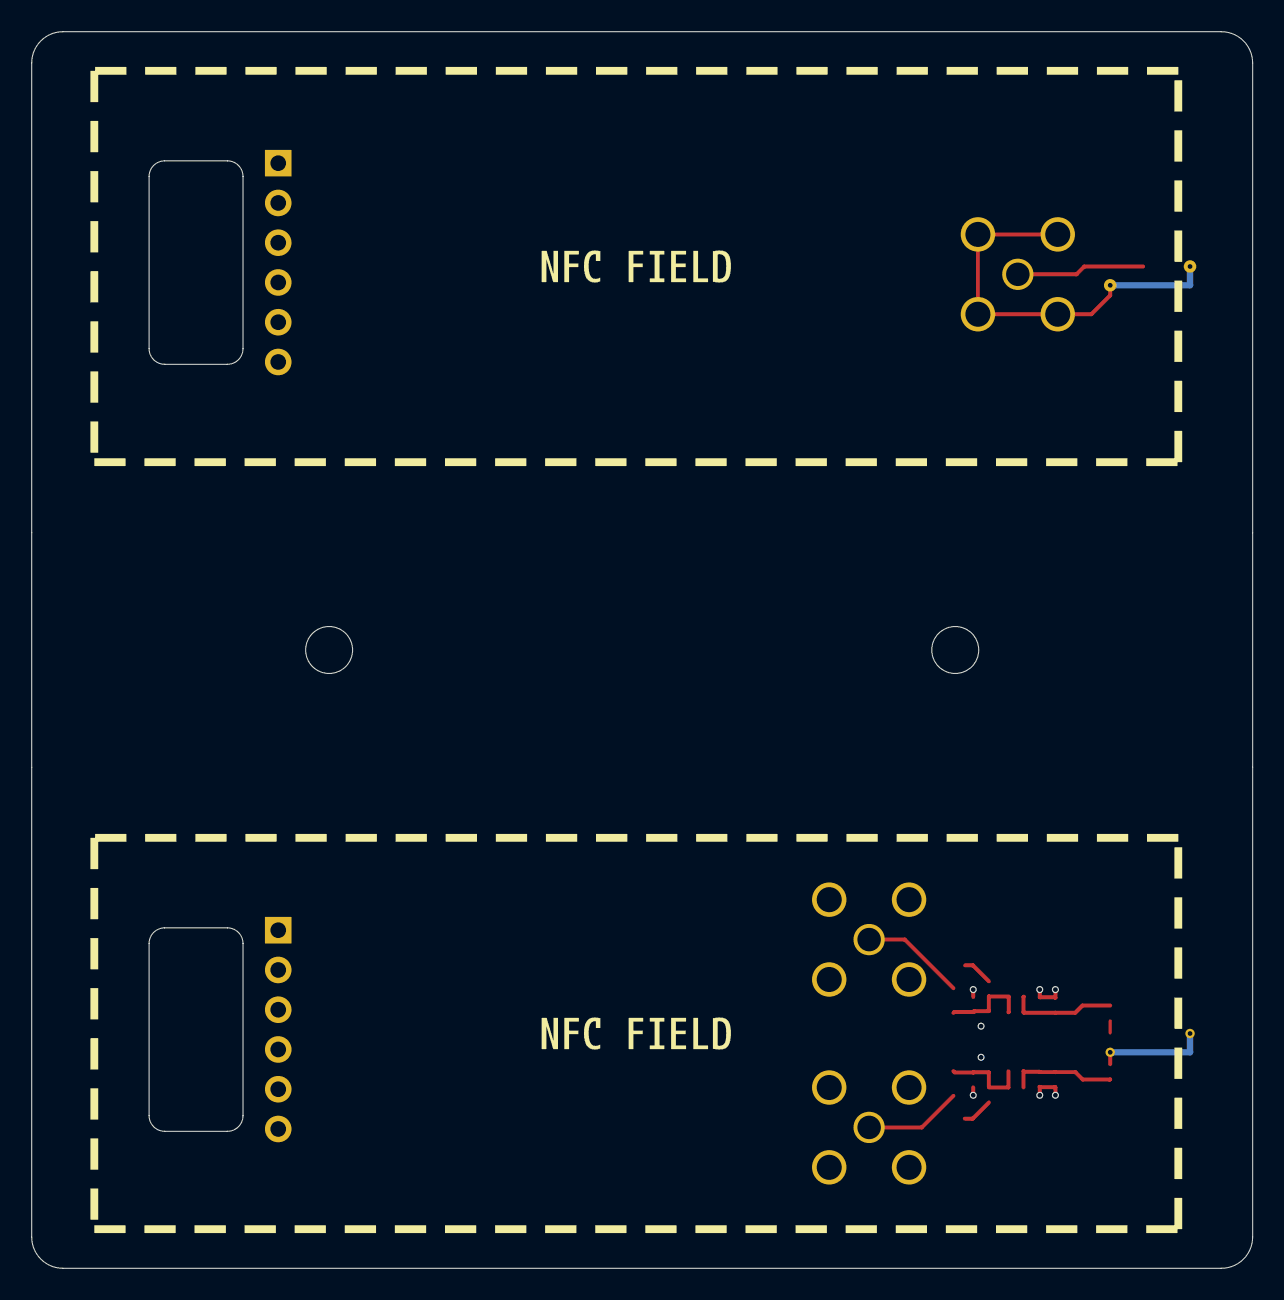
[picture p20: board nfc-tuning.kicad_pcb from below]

Board: 4 copper layers, 78.0 x 79.0 mm, 31 parts (2 on the bottom side), 12 nets.

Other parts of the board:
J5, J5#2: Mic Adafruit; SPH0645LM4H
kibuzzard-6A730F68: G***; kibuzzard-6A730F68
kibuzzard-6A730F73: G***; kibuzzard-6A730F73
kibuzzard-6A70487D, kibuzzard-6A70487D#2: G***; kibuzzard-6A70487D

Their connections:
GND: J5#2.2; also elsewhere on the board

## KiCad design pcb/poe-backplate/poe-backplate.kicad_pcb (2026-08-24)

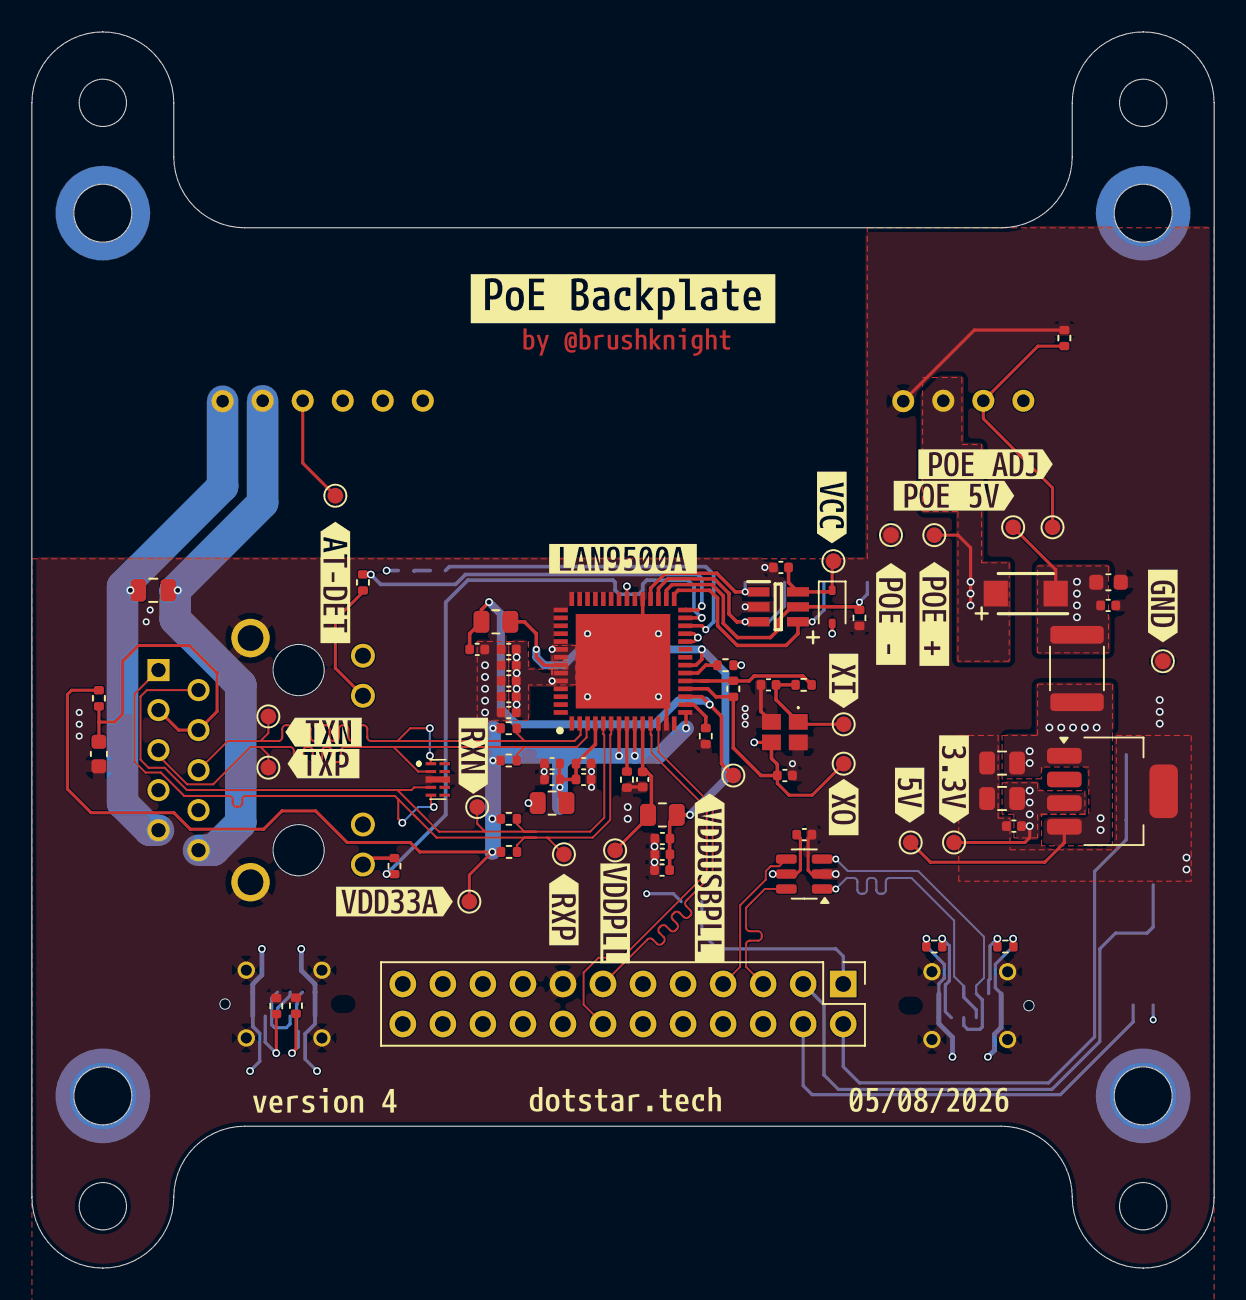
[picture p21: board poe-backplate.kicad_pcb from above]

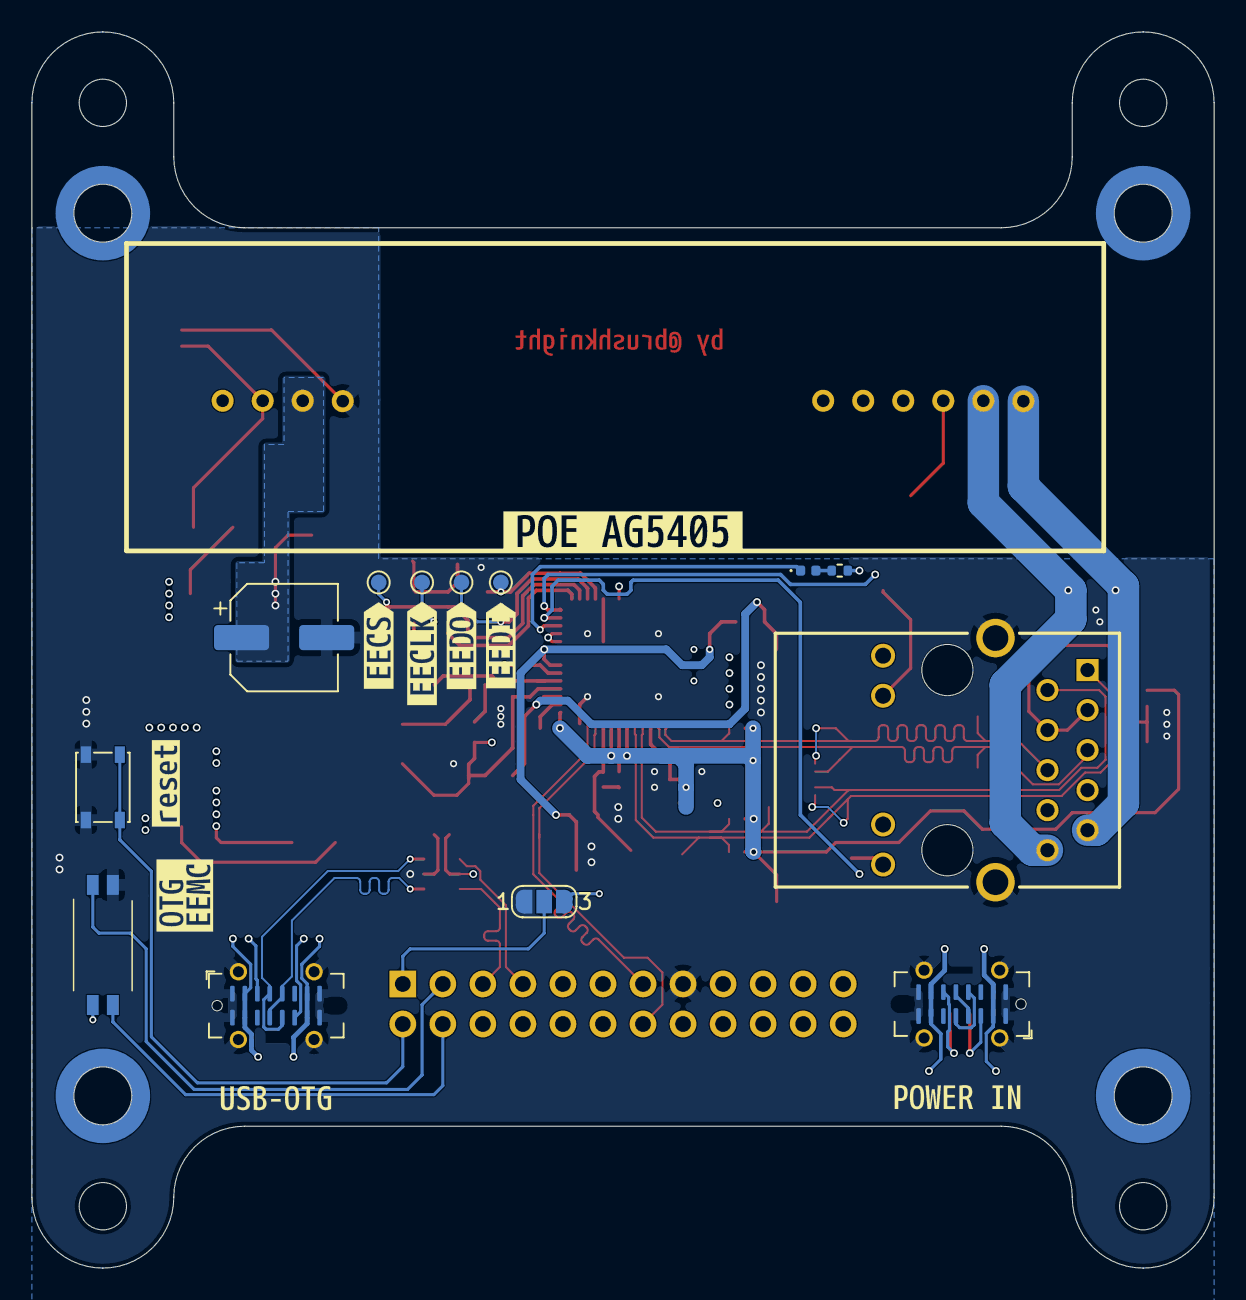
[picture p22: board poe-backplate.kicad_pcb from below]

Board: 6 copper layers, 75.0 x 78.4 mm, 125 parts (27 on the bottom side), 51 nets.

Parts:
C1, C2, C3, C4, C5, C6, C7, C8, C9, C11, C12, C13, C14, C16, C20, C22, C26: 100nF; C_0402_1005Metric
C10: 1uF; C_0402_1005Metric
C15, C18: 24pF; C_0402_1005Metric
C17, C19: 1uF; C_0805_2012Metric
C21: 1uF; C_0603_1608Metric
C23: 22nF; C_0603_1608Metric
C24: 10nF; C_0805_2012Metric
C25: 470µF; CP_Elec_6.3x7.7
D1: GREEN; LED_0402_1005Metric
D2: B0540WS; D_SOD-323
D3: SS54F; SODFL4626X120N
D4: RCLAMP0524PATCT
FB1, FB2, FB3: BLM21PG221SN1D; R_0805_2012Metric
FB4: CBM453215U101T; R_1812_4532Metric
H1, H2, H3, H4: MountingHole_Pad; 9774030151R
IC1: LAN9500A-ABZJ; QFN50P800X800X100-57N-D
IC2: 93LC66AT-I_OT; SOT95P270X145-6N
J3, J4: USB_C_Receptacle_USB2.0_14P; USB_C_Receptacle_G-Switch_GT-USB-7051x
J5: Conn_02x12_Counter_Clockwise; PinHeader_2x12_P2.54mm_Vertical
JP1: SolderJumper_3_Open; SolderJumper-3_P1.3mm_Open_RoundedPad1.0x1.5mm_NumberLabels
POE1: AG5405
R1, R2: 12K; R_0402_1005Metric
R3, R5: 0; R_0402_1005Metric
R4: 1M; R_0402_1005Metric
R6, R12, R13: 3.3K; R_0402_1005Metric
R7: 10K; R_0402_1005Metric
R8, R10: 56K; R_0402_1005Metric
R9, R11: 5.1K; R_0402_1005Metric
R14: 10; R_0402_1005Metric
R15, R16, R17, R18: 49.9; R_0402_1005Metric
R19: 50K; R_0402_1005Metric
S6: 218-2LPSTRF; 2182LPSTRF
SW1: power reset; SW_SPST_PTS810
TP1, TP2, TP3, TP4, TP5, TP6, TP7, TP8, TP9, TP10, TP11, TP12, TP13, TP14, TP15, TP16, TP17, TP18, TP19, TP20, TP21, TP22: TestPoint; TestPoint_Pad_D1.0mm
U1: LP38693MP-3.3; SOT-223-5
U2: HY931147C
U5: USBLC6-2SC6; SOT-23-6
Y1: ECS-250-18-36B2-CTY-TR; ECS2501836B2CTYTR
kibuzzard-6A58C3F0: G***; kibuzzard-6A58C3F0
kibuzzard-6A58C4AC: G***; kibuzzard-6A58C4AC
kibuzzard-6A58C49B: G***; kibuzzard-6A58C49B
kibuzzard-6A58C460: G***; kibuzzard-6A58C460
kibuzzard-6A266BA6: G***; kibuzzard-6A266BA6
kibuzzard-6A266BBE: G***; kibuzzard-6A266BBE
kibuzzard-6A416FC5: G***; kibuzzard-6A416FC5
kibuzzard-6A416FFB: G***; kibuzzard-6A416FFB
kibuzzard-6A7327CD: G***; kibuzzard-6A7327CD
kibuzzard-6A7327D6: G***; kibuzzard-6A7327D6
kibuzzard-68D6D404: G***; kibuzzard-68D6D404
kibuzzard-68D6D564: G***; kibuzzard-68D6D564
kibuzzard-68DA6D8B: G***; kibuzzard-68DA6D8B
kibuzzard-68DA50C8: G***; kibuzzard-68DA50C8
kibuzzard-68DA50CF: G***; kibuzzard-68DA50CF
kibuzzard-68DA50D5: G***; kibuzzard-68DA50D5
kibuzzard-68DA50DD: G***; kibuzzard-68DA50DD
kibuzzard-68DA54A3: G***; kibuzzard-68DA54A3
kibuzzard-68DA512A: G***; kibuzzard-68DA512A
kibuzzard-68DA5225: G***; kibuzzard-68DA5225
kibuzzard-68DA5440: G***; kibuzzard-68DA5440
kibuzzard-68DA5448: G***; kibuzzard-68DA5448
kibuzzard-68DA5505: G***; kibuzzard-68DA5505
kibuzzard-68DAA144: G***; kibuzzard-68DAA144
kibuzzard-697B6E2E: G***; kibuzzard-697B6E2E
kibuzzard-697B6E24: G***; kibuzzard-697B6E24
kibuzzard-697F85B0: G***; kibuzzard-697F85B0
kibuzzard-697F8524: G***; kibuzzard-697F8524
kibuzzard-6978AB6C: G***; kibuzzard-6978AB6C
kibuzzard-6978AB9F: G***; kibuzzard-6978AB9F
kibuzzard-6978AB59: G***; kibuzzard-6978AB59
kibuzzard-6985C4FD: G***; kibuzzard-6985C4FD
kibuzzard-6985C516: G***; kibuzzard-6985C516

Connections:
+3.3V: C1.2, C2.2, C4.2, C6.2, C8.2, C19.2, C20.2, D2.2 (A), FB1.1, IC1.24 (NRESET), IC1.25 (VDD33IO_1), IC1.35 (VDD33IO_2), IC1.48 (VDD33IO_3), IC1.49 (TEST1), IC1.51 (VDD33IO_4), IC1.52 (VDD33IO_5), JP1.3 (B), R3.1, R6.2, TP13.1 (1_1), U1.3 (OUT), U2.P$11 (Y+), U2.P$13 (G+)
+5V: C17.2, C26.2, FB4.2, J3.A4 (VBUS), J3.A9 (VBUS), J3.B4 (VBUS), J3.B9 (VBUS), J5.16, R8.2, R10.2, S6.3, TP12.1 (1_1), U1.1 (EN), U1.4 (IN), U5.5 (VBUS)
/PoE/ETH1_LEDG: IC1.27 (NLNKA_LED/GPIO9), R12.2
/PoE/ETH1_LEDY: IC1.28 (NSPD_LED/GPIO10), R13.2
/PoE/POE_5V: C21.1, C22.1, D3.1 (K), FB4.1, J4.A4 (VBUS), J4.A9 (VBUS), J4.B4 (VBUS), J4.B9 (VBUS), TP10.1 (1_1)
/PoE/POE_VIN+: C24.1, POE1.1 (VIN+), U2.P$9 (V+)
/PoE/POE_VIN-: C24.2, POE1.2 (VIN-), U2.P$10 (V-)
/PoE/RXN: D4.4 (INPUT_LINES_3), IC1.5 (RXN), R15.2, TP21.1 (1_1), U2.P$2 (RX-)
/PoE/RXP: D4.5 (INPUT_LINES_4), IC1.6 (RXP), R16.2, TP22.1 (1_1), U2.P$1 (RX+)
/PoE/TXN: D4.1 (INPUT_LINES_1), IC1.2 (TXN), R17.2, TP19.1 (1_1), U2.P$6 (TX-)
/PoE/TXP: D4.2 (INPUT_LINES_2), IC1.3 (TXP), R18.2, TP20.1 (1_1), U2.P$5 (TX+)
/PoE/VDD33A: C3.2, C5.2, C7.2, C9.2, FB1.2, IC1.4 (VDD33A_1), IC1.7 (NC_1), IC1.9 (VDD33A_2), IC1.15 (VDD33A_3), R14.1, R15.1, R16.1, R17.1, R18.1, TP16.1 (1_1)
/USB to Ethernet/CRYSTAL_XI: C18.2, IC1.18 (XI), R4.2, TP14.1 (1_1), Y1.3 (OUT/IN)
/USB to Ethernet/CRYSTAL_XO: IC1.19 (XO), R4.1, R5.1
/USB to Ethernet/EECLK_GPIO3: IC1.29 (EECLK/PWR_SEL), IC2.4 (CLK), TP5.1 (1_1)
/USB to Ethernet/EECS_GPIO0: IC1.30 (EECS), IC2.5 (CS), R7.1, TP4.1 (1_1)
/USB to Ethernet/EEDI_GPIO1: IC1.32 (EEDI), IC2.1 (DO), TP2.1 (1_1)
/USB to Ethernet/EEDO_GPIO2: IC1.31 (EEDO/AUTOMDIX_EN), IC2.3 (DI), TP3.1 (1_1)
/USB to Ethernet/ETH1_LED_FDX: D1.1 (K), IC1.26 (NFDX_LED/GPIO8)
/USB to Ethernet/GLOBAL_EN: J5.2, SW1.1
/USB to Ethernet/OTG_MODE_SW1: J5.3, S6.2
/USB to Ethernet/USBDN: IC1.11 (USBDM), J5.14
/USB to Ethernet/USBDP: IC1.12 (USBDP), J5.13
/USB to Ethernet/USBD_POGO_N: J5.5, U5.6 (I/O1)
/USB to Ethernet/USBD_POGO_P: J5.7, U5.4 (I/O2)
/USB to Ethernet/USB_D+: J3.A6 (D+), J3.B6 (D+), U5.3 (I/O2)
/USB to Ethernet/USB_D-: J3.A7 (D-), J3.B7 (D-), U5.1 (I/O1)
/USB to Ethernet/USB_OTG_SWITCH: J5.1, JP1.2 (C)
/USB to Ethernet/VDDCORE: C10.2, C11.2, C12.2, FB2.1, FB3.1, IC1.21 (VDDCORE_1), IC1.50 (VDDCORE_2)
/USB to Ethernet/VDDPLL: C14.2, FB3.2, IC1.10 (VDDPLL), TP18.1 (1_1)
/USB to Ethernet/VDDUSBPLL: C13.2, FB2.2, IC1.17 (VDDUSBPLL), TP17.1 (1_1)
/USB to Ethernet/nRPIBOOT: J5.4, S6.4
GND: C1.1, C2.1, C3.1, C4.1, C5.1, C6.1, C7.1, C8.1, C9.1, C10.1, C11.1, C12.1, C13.1, C14.1, C15.1, C16.1, C17.1, C18.1, C19.1, C20.1, C21.2, C22.2, C23.2, C25.2, C26.1, D4.3 (GND_1), D4.8 (GND_2), IC1.13 (TEST2), IC1.33 (TEST3), IC1.57 (VSS), IC2.2 (VSS), J3.A1 (GND), J3.A12 (GND), J3.B1 (GND), J3.B12 (GND), J3.S1 (SHIELD), J4.A1 (GND), J4.A12 (GND), J4.B1 (GND), J4.B12 (GND), J4.S1 (SHIELD), J5.15, JP1.1 (A), POE1.7 (-VDC), R1.1, R2.1, R7.2, R9.2, R11.2, R19.2, S6.1, SW1.2, TP1.1 (1_1), TP8.1 (1_1), U1.5 (GND), U2.GND1, U2.GND2, U5.2 (GND), Y1.2 (GND_1), Y1.4 (GND_2)
unnamed: D1.2 (A), R6.1
unnamed: C16.2, D2.1 (K), IC2.6 (VCC), TP6.1 (1_1)
unnamed: C25.1, D3.2 (A), POE1.8 (+VDC_), TP9.1 (1_1)
unnamed: IC1.8 (EXRES), R1.2
unnamed: IC1.16 (USBRBIAS), R2.2
unnamed: IC1.20 (VBUS_DET), R3.2
unnamed: J3.A5 (CC1), R8.1
unnamed: J3.B5 (CC2), R10.1
unnamed: J4.A5 (CC1), R9.1
unnamed: J4.B5 (CC2), R11.1
unnamed: J4.A6 (D+), J4.B6 (D+)
unnamed: J4.A7 (D-), J4.B7 (D-)
unnamed: POE1.9 (ADJ), R19.1, TP7.1 (1_1)
unnamed: POE1.3 (AT-DET), TP11.1 (1_1)
unnamed: R12.1, U2.P$14 (G-)
unnamed: C23.1, R14.2, U2.P$3 (RXCT), U2.P$4 (TXCT)
unnamed: R13.1, U2.P$12 (Y-)
unnamed: C15.2, R5.2, TP15.1 (1_1), Y1.1 (IN/OUT)

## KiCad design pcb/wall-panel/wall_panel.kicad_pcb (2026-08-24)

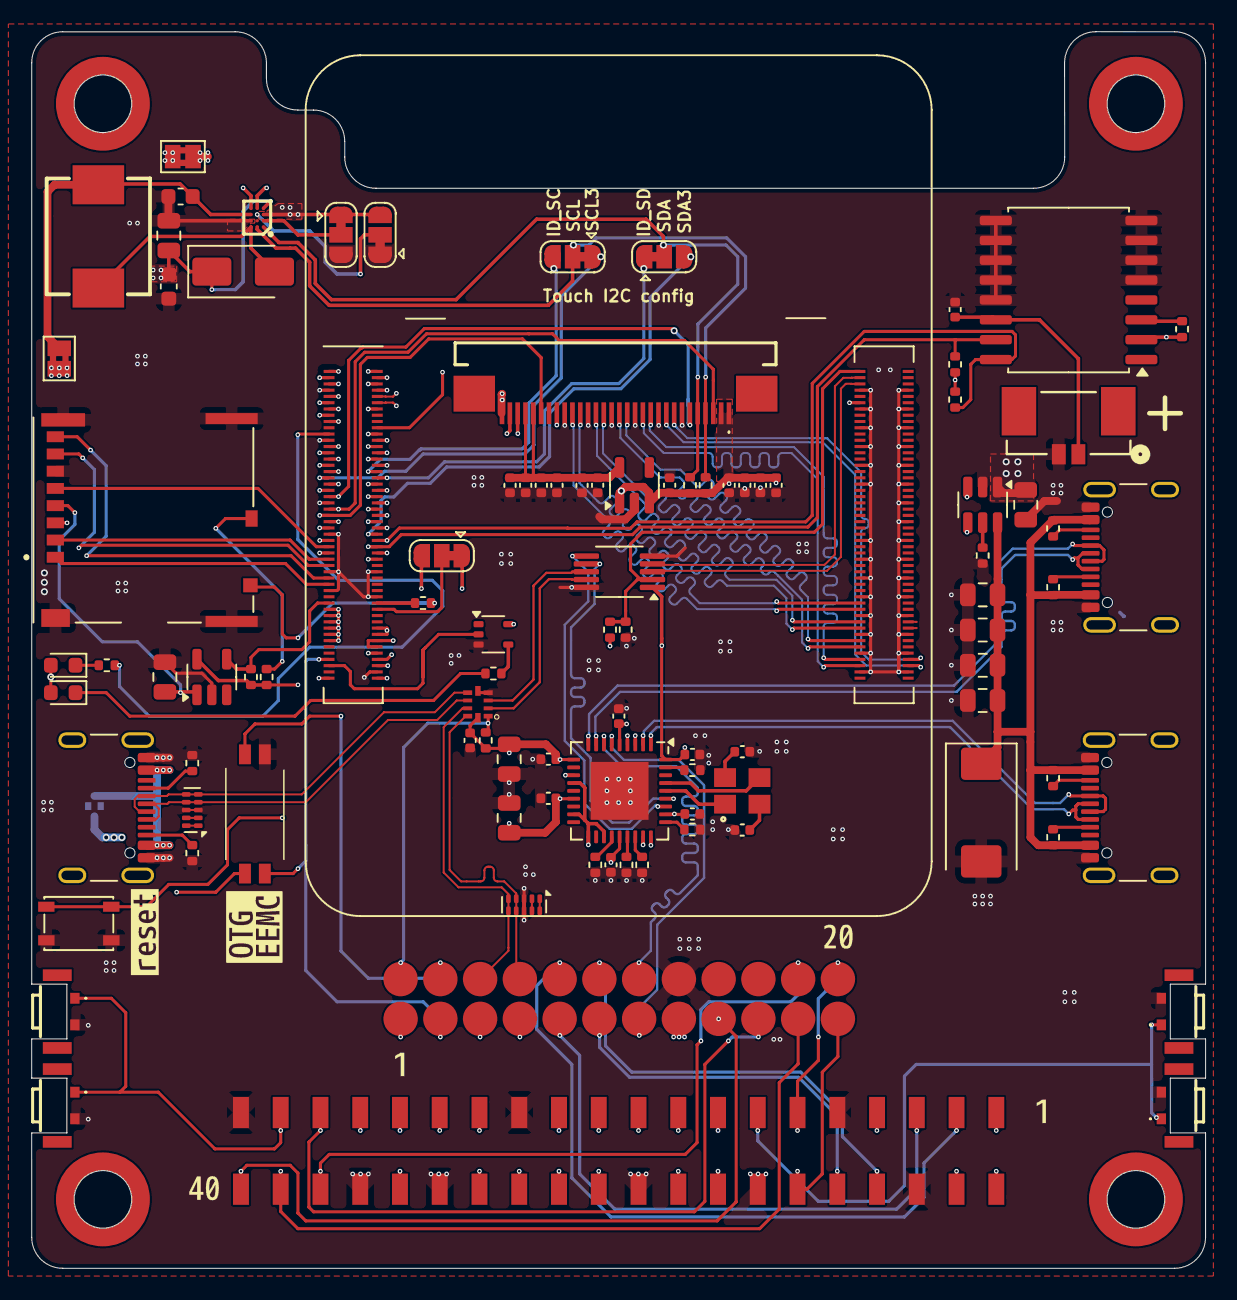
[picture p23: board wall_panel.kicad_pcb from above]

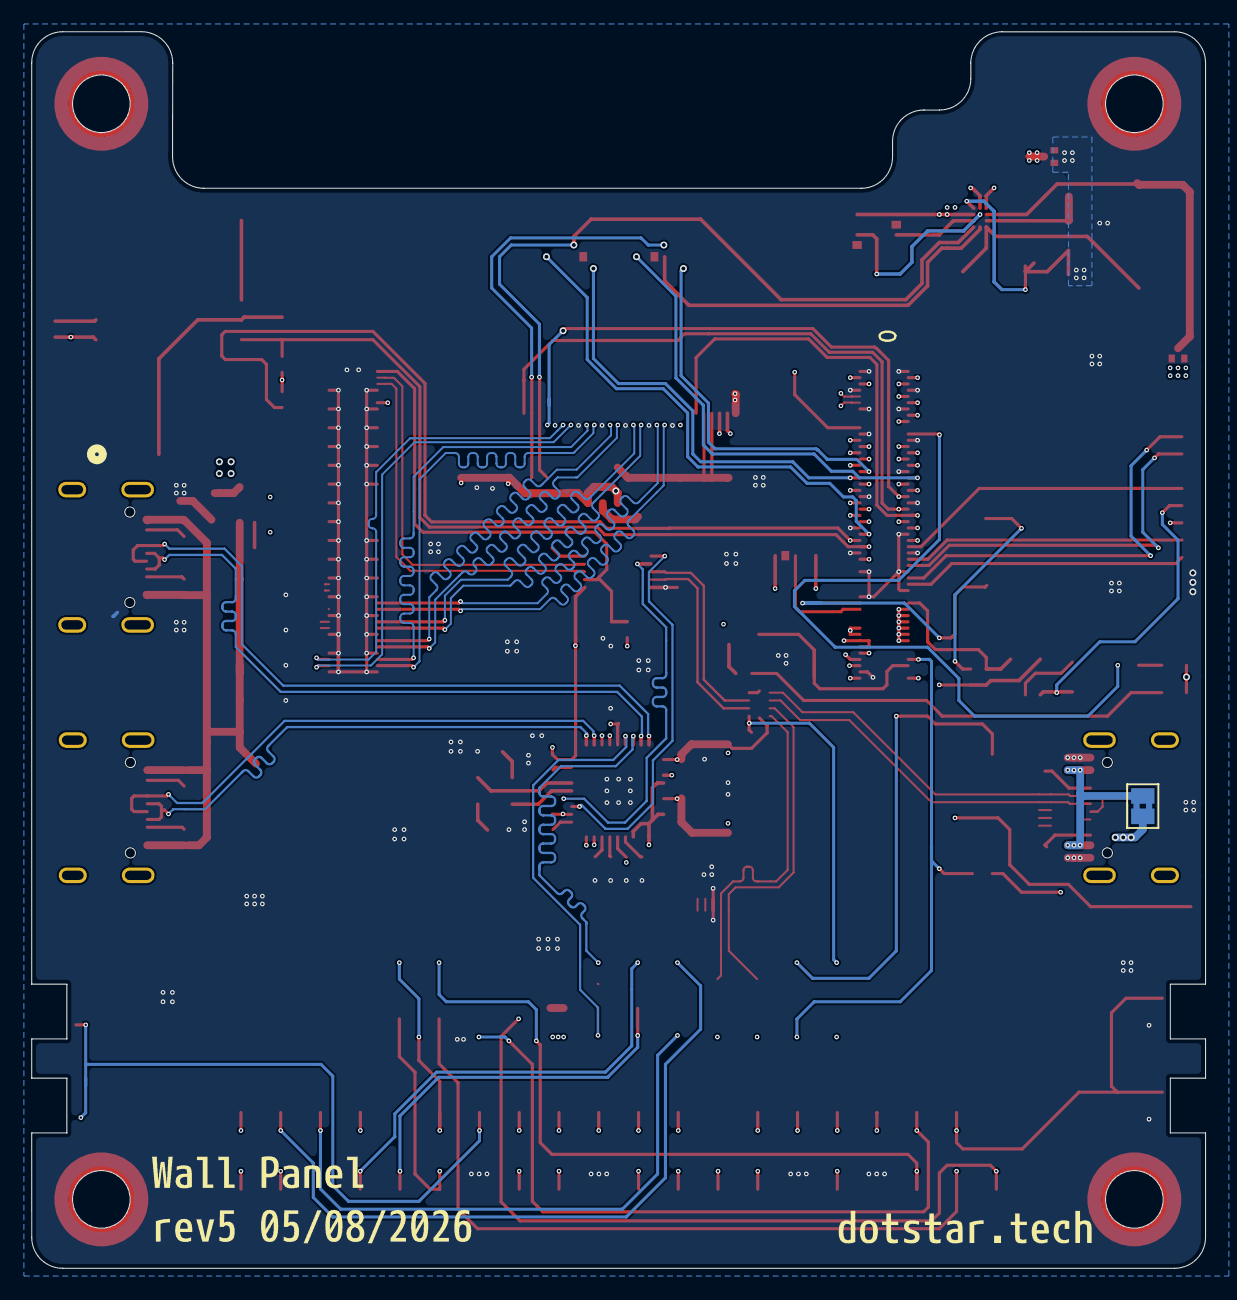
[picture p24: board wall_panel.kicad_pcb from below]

Board: 8 copper layers, 75.0 x 79.0 mm, 117 parts (4 on the bottom side), 119 nets.

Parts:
C1, C2: 27pF; C_0402_1005Metric
C3, C4, C11, C13, C14, C15, C16, C31: 10u; C_0805_2012Metric
C5, C6, C7, C8, C9, C10, C17, C22, C23, C24, C27, C28, C34: 100n; C_0402_1005Metric
C12: 100uF; CP_EIA-7343-31_Kemet-D
C20, C21: 10uF; C_0402_1005Metric
C25, C26, C29, C30: 1uF; C_0402_1005Metric
C35: 2.2uF; C_0603_1608Metric
C36: 22uF; C_0805_2012Metric
C37: 1uF; C_0603_1608Metric
D1: LED Green; LED_0603_1608Metric
D2: LED Red; LED_0603_1608Metric
D5: SS34; D_SMA
H1, H2, H3, H4: MountingHole_Pad; 9774030151R
IC1: TS3USB221RSER; RSE_R-PUQFN-N10_
IC2: LM3630ATMX; BGA12C40P3X4_139X191X68
J1, J2, J17: USB_C_Receptacle_USB2.0_14P; USB_C_Receptacle_GCT_USB4105-xx-A_16P_TopMnt_Horizontal
J3: pogo_1-1_3; pogo_1x3
J4: Conn_01x02_Socket; CONN02_533984002_MOL
J5: SFV30R-4STBE1HLF; SFV30R4STBE1HLF
J7: pogo_1-4_6; pogo_1x3
J8: pogo_1-7_9; pogo_1x3
J9: pogo_1-10_12; pogo_1x3
J10: THD-20-R; PM254-2-20-WS-8.5
J11: pogo_2-1_3; pogo_1x3
J12: pogo_2-4_6; pogo_1x3
J13: pogo_2-7_9; pogo_1x3
J14: pogo_2-10_12; pogo_1x3
J16: Micro_SD_Card_Det; SDCARD_MOLEX_503398-1892
JP1, JP3, JP4, JP7, JP8: GPIO reference; SolderJumper-3_P1.3mm_Bridged12_RoundedPad1.0x1.5mm
JP2: Jumper_2_Small_Bridged; SolderJumper-2_P1.3mm_Bridged2Bar_Pad1.0x1.5mm
JP5, JP6: SolderJumper_2_Bridged; SolderJumper-2_P1.3mm_Bridged2Bar_Pad1.0x1.5mm
L2: 10uH; IND-SMD_L7.4-W6.6
Module1: ComputeModule4; Raspberry-Pi-4-Compute-Module
R1, R2, R14, R15: 2.2K 1%; R_0402_1005Metric
R3, R4, R5, R7: 36K 1%; R_0402_1005Metric
R6, R22: 12K 1%; R_0402_1005Metric
R8, R9: 5.1k; R_0402_1005Metric
R10, R12, R25, R26: 56K; R_0402_1005Metric
R11: 15K 1%; R_0402_1005Metric
R13: 10K; R_0402_1005Metric
R16, R19: 1k; R_0402_1005Metric
R17: 100K; R_0402_1005Metric
R20, R21: nf; R_0402_1005Metric
R23, R24: 4.7k; R_0402_1005Metric
S1, S3, S4, S5: SKSLLBE010
S6: 218-2LPSTRF; 2182LPSTRF
SW1: power reset; SW_SPST_PTS810
U1: FSUSB42MUX; MSOP-10_3x3mm_P0.5mm
U2: USB2514B-I/M2; QFN-36-1EP_6x6mm_P0.5mm_EP3.7x3.7mm
U3, U13: TPD4EUSB30; USON-10_2.5x1.0mm_P0.5mm
U4: AP22653W6; SOT-23-6
U5: DS3231M; SOIC-16W_7.5x10.3mm_P1.27mm
U7: LP5907MFX-2.8; SOT-23-5
U9: 74LVC1G07SE-7; SOT-353_SC-70-5
U10: RT9742GGJ5; SOT-23-5
Y1: ABM8G-24.000MHZ-18-D2Y-T; ABM8G
kibuzzard-6A266BA6: G***; kibuzzard-6A266BA6
kibuzzard-6A266BBE: G***; kibuzzard-6A266BBE
kibuzzard-6A732F3C: G***; kibuzzard-6A732F3C
kibuzzard-6A2675C8, kibuzzard-6A2675C8#2: G***; kibuzzard-6A2675C8
kibuzzard-6A2675F6: G***; kibuzzard-6A2675F6
kibuzzard-6A267621: G***; kibuzzard-6A267621
kibuzzard-68AC3314: G***; kibuzzard-68AC3314
kibuzzard-6981E919: G***; kibuzzard-6981E919

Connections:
+2.8v: C21.2, C22.2, C24.1, C26.1, C28.1, C30.1, J5.4 (VCI_4), J5.5 (IOVCC_5), U7.5 (OUT)
+3.3V: C3.1, C4.1, C5.1, C6.1, C7.1, C8.1, C9.1, C10.1, C20.2, C23.1, C25.1, C27.1, C29.1, C34.1, D1.2 (A), D2.2 (A), IC1.10 (VCC), IC2.C1 (PWM), J5.29 (TP_VCI_29), J5.30 (TP_IOVCC_30), J10.1, J10.17, JP1.1 (A), JP7.3 (B), JP8.1 (A), Module1.84 (+3.3v_(Output)), Module1.86 (+3.3v_(Output)), R13.2, R14.1, R15.1, R17.1, R20.1, R22.1, R23.1, R24.1, U1.1 (VCC), U2.5 (VDDA33), U2.10 (VDDA33), U2.15 (VDD33), U2.23 (VDD33), U2.27 (VBUS_DET), U2.29 (VDDA33), U2.36 (VDDA33), U5.2 (VCC), U7.1 (IN), U7.3 (EN), U9.5 (VCC), U10.5 (IN)
+5V: C11.1, J10.2, J10.4, JP2.2 (B), JP5.1 (A), Module1.77 (+5v_(Input)), Module1.79 (+5v_(Input)), Module1.81 (+5v_(Input)), Module1.83 (+5v_(Input)), Module1.85 (+5v_(Input)), Module1.87 (+5v_(Input)), S6.3, U4.1 (IN)
/CM4_GPIO ( Ethernet, GPIO, SDCARD)/+1.8v: JP1.3 (B), Module1.88 (+1.8v_(Output)), Module1.90 (+1.8v_(Output))
/CM4_GPIO ( Ethernet, GPIO, SDCARD)/EEPROM_nWP: J11.3, Module1.20 (EEPROM_nWP)
/CM4_GPIO ( Ethernet, GPIO, SDCARD)/GLOBAL_EN: J11.1, Module1.99 (Global_EN), SW1.1
/CM4_GPIO ( Ethernet, GPIO, SDCARD)/GPIO2: J7.2, J10.3, Module1.58 (GPIO2), R23.2, U5.15 (SDA)
/CM4_GPIO ( Ethernet, GPIO, SDCARD)/GPIO3: J10.5, J12.2, Module1.56 (GPIO3), R24.2, U5.16 (SCL)
/CM4_GPIO ( Ethernet, GPIO, SDCARD)/GPIO4: J10.7, JP3.3 (B), Module1.54 (GPIO4)
/CM4_GPIO ( Ethernet, GPIO, SDCARD)/GPIO5: J10.29, JP4.3 (B), Module1.34 (GPIO5)
/CM4_GPIO ( Ethernet, GPIO, SDCARD)/GPIO6: J10.31, Module1.30 (GPIO6)
/CM4_GPIO ( Ethernet, GPIO, SDCARD)/GPIO7: J10.26, Module1.37 (GPIO7)
/CM4_GPIO ( Ethernet, GPIO, SDCARD)/GPIO8: J10.24, Module1.39 (GPIO8)
/CM4_GPIO ( Ethernet, GPIO, SDCARD)/GPIO9: J10.21, Module1.40 (GPIO9)
/CM4_GPIO ( Ethernet, GPIO, SDCARD)/GPIO10: J10.19, Module1.44 (GPIO10)
/CM4_GPIO ( Ethernet, GPIO, SDCARD)/GPIO11: J10.23, Module1.38 (GPIO11)
/CM4_GPIO ( Ethernet, GPIO, SDCARD)/GPIO12: J10.32, Module1.31 (GPIO12)
/CM4_GPIO ( Ethernet, GPIO, SDCARD)/GPIO13: J10.33, Module1.28 (GPIO13)
/CM4_GPIO ( Ethernet, GPIO, SDCARD)/GPIO14: J7.3, J10.8, Module1.55 (GPIO14)
/CM4_GPIO ( Ethernet, GPIO, SDCARD)/GPIO15: J10.10, J12.3, Module1.51 (GPIO15)
/CM4_GPIO ( Ethernet, GPIO, SDCARD)/GPIO16: J9.2, J10.36, Module1.29 (GPIO16)
/CM4_GPIO ( Ethernet, GPIO, SDCARD)/GPIO17: J9.3, J10.11, Module1.50 (GPIO17)
/CM4_GPIO ( Ethernet, GPIO, SDCARD)/GPIO18: J10.12, J14.3, Module1.49 (GPIO18)
/CM4_GPIO ( Ethernet, GPIO, SDCARD)/GPIO19: J10.35, J14.1, Module1.26 (GPIO19)
/CM4_GPIO ( Ethernet, GPIO, SDCARD)/GPIO20: J10.38, J14.2, Module1.27 (GPIO20)
/CM4_GPIO ( Ethernet, GPIO, SDCARD)/GPIO21: J10.40, J13.3, Module1.25 (GPIO21)
/CM4_GPIO ( Ethernet, GPIO, SDCARD)/GPIO22: J10.15, Module1.46 (GPIO22)
/CM4_GPIO ( Ethernet, GPIO, SDCARD)/GPIO23: J5.6 (RESET_6), J10.16, Module1.47 (GPIO23)
/CM4_GPIO ( Ethernet, GPIO, SDCARD)/GPIO24: J5.28 (TP_RESET_28), J10.18, Module1.45 (GPIO24)
/CM4_GPIO ( Ethernet, GPIO, SDCARD)/GPIO25: J5.25 (TP_INT_25), J10.22, Module1.41 (GPIO25)
/CM4_GPIO ( Ethernet, GPIO, SDCARD)/GPIO26: J10.37, Module1.24 (GPIO26), S4.1, S5.1
/CM4_GPIO ( Ethernet, GPIO, SDCARD)/GPIO27: J10.13, Module1.48 (GPIO27), S1.1, S3.1
/CM4_GPIO ( Ethernet, GPIO, SDCARD)/GPIO_VREF: JP1.2 (C), Module1.78 (GPIO_VREF(1.8v/3.3v_Input))
/CM4_GPIO ( Ethernet, GPIO, SDCARD)/ID_SC: J10.28, JP4.1 (A), Module1.35 (ID_SC)
/CM4_GPIO ( Ethernet, GPIO, SDCARD)/ID_SD: J10.27, JP3.1 (A), Module1.36 (ID_SD)
/CM4_GPIO ( Ethernet, GPIO, SDCARD)/OTG_MODE_SW1: J3.2, R2.1, S6.2
/CM4_GPIO ( Ethernet, GPIO, SDCARD)/Reserved: Module1.76 (Reserved), R21.1
/CM4_GPIO ( Ethernet, GPIO, SDCARD)/SD_CLK: J16.5 (CLK), Module1.57 (SD_CLK)
/CM4_GPIO ( Ethernet, GPIO, SDCARD)/SD_CMD: J16.3 (CMD), Module1.62 (SD_CMD)
/CM4_GPIO ( Ethernet, GPIO, SDCARD)/SD_DAT0: J16.7 (DAT0), Module1.63 (SD_DAT0)
/CM4_GPIO ( Ethernet, GPIO, SDCARD)/SD_DAT1: J16.8 (DAT1), Module1.67 (SD_DAT1)
/CM4_GPIO ( Ethernet, GPIO, SDCARD)/SD_DAT2: J16.1 (DAT2), Module1.69 (SD_DAT2)
/CM4_GPIO ( Ethernet, GPIO, SDCARD)/SD_DAT3: J16.2 (DAT3/CD), Module1.61 (SD_DAT3)
/CM4_GPIO ( Ethernet, GPIO, SDCARD)/SD_PWR: C31.1, J16.4 (VDD), U10.1 (OUT)
/CM4_GPIO ( Ethernet, GPIO, SDCARD)/SD_PWR_ON: Module1.75 (SD_PWR_ON), R22.2, U10.4 (EN)
/CM4_GPIO ( Ethernet, GPIO, SDCARD)/USB_OTG_SWITCH: IC1.1 (S), J3.1, R17.2
/CM4_GPIO ( Ethernet, GPIO, SDCARD)/nActivity_LED: Module1.21 (PI_nLED_Activity), R16.2
/CM4_GPIO ( Ethernet, GPIO, SDCARD)/nPWR_LED: Module1.95 (nPI_LED_PWR), U9.2
/CM4_GPIO ( Ethernet, GPIO, SDCARD)/nRPIBOOT: J11.2, Module1.93 (nRPIBOOT), S6.4
/CM4_HighSpeed/BACKLIGHT_POWER: J5.1 (LEDA_1), JP6.2 (B)
/CM4_HighSpeed/DSI1_C_N: J5.17 (CLKN_17), Module1.187 (DSI1_C_N)
/CM4_HighSpeed/DSI1_C_P: J5.16 (CLKP_16), Module1.189 (DSI1_C_P)
/CM4_HighSpeed/DSI1_D0_N: J5.11 (MIPI_0N_11), Module1.175 (DSI1_D0_N)
/CM4_HighSpeed/DSI1_D0_P: J5.10 (MIPI_0P_10), Module1.177 (DSI1_D0_P)
/CM4_HighSpeed/DSI1_D1_N: J5.14 (MIPI_1N_14), Module1.181 (DSI1_D1_N)
/CM4_HighSpeed/DSI1_D1_P: J5.13 (MIPI_1P_13), Module1.183 (DSI1_D1_P)
/CM4_HighSpeed/DSI1_D2_N: J5.20 (MIPI_2N__20), Module1.193 (DSI1_D2_N)
/CM4_HighSpeed/DSI1_D2_P: J5.19 (MIPI_2P_19), Module1.195 (DSI1_D2_P)
/CM4_HighSpeed/DSI1_D3_N: J5.23 (MIPI_3N_23), Module1.194 (DSI1_D3_N)
/CM4_HighSpeed/DSI1_D3_P: J5.22 (MIPI_3P_22), Module1.196 (DSI1_D3_P)
/CM4_HighSpeed/LEDK1: IC2.D2 (ILED2), J5.2 (LEDK1_2)
/CM4_HighSpeed/LEDK2: IC2.D3 (ILED1), J5.3 (LEDK2_3)
/CM4_HighSpeed/TOUCH_SCL: IC2.A2 (SCL), J5.27 (TP_SCL_27), JP4.2 (C), R15.2
/CM4_HighSpeed/TOUCH_SDA: IC2.A1 (SDA), J5.26 (TP_SDA_26), JP3.2 (C), R14.2
/CM4_HighSpeed/USB2_N: Module1.103 (USB2_N), U1.4 (D_N)
/CM4_HighSpeed/USB2_P: Module1.105 (USB2_P), U1.3 (D_P)
/CM4_HighSpeed/USBOTG_ID: Module1.101 (USB_OTG_ID), R1.1, R2.2, U1.2 (SEL)
/RTC , Wakeup, FAN/nRTC_INT: R13.1, U5.3 (~INT/SQW)
/USB2-HUB/HD1_N: J17.A7 (D-), J17.B7 (D-), U2.1 (USBDM_DN1/PRT_DIS_M1)
/USB2-HUB/HD1_P: J17.A6 (D+), J17.B6 (D+), U2.2 (USBDP_DN1/PRT_DIS_P1)
/USB2-HUB/HD3_N: J13.1, U2.6 (USBDM_DN3/PRT_DIS_M3)
/USB2-HUB/HD3_P: J8.1, U2.7 (USBDP_DN3/PRT_DIS_P3)
/USB2-HUB/HD4_N: J2.A7 (D-), J2.B7 (D-), U2.8 (USBDM_DN4/PRT_DIS_M4)
/USB2-HUB/HD4_P: J2.A6 (D+), J2.B6 (D+), U2.9 (USBDP_DN4/PRT_DIS_P4)
/USB2-HUB/PWR1: U2.12 (PRTPWR1/BC_EN1), U4.3 (EN)
/USB2-HUB/USBD_N: IC1.3 (D-), U1.8 (HSD1_M)
/USB2-HUB/USBD_OTG_N: IC1.6 (2D-), J1.A7 (D-), J1.B7 (D-), U3.5 (D2-), U3.6
/USB2-HUB/USBD_OTG_P: IC1.7 (2D+), J1.A6 (D+), J1.B6 (D+), U3.4 (D2+), U3.7
/USB2-HUB/USBD_P: IC1.2 (D+), U1.9 (HSD1_P)
/USB2-HUB/USBD_POGO_N: IC1.8 (1D-), J3.3, U13.5 (D2-), U13.6
/USB2-HUB/USBD_POGO_P: IC1.9 (1D+), J7.1, U13.4 (D2+), U13.7
/USB2-HUB/USBH_N: U1.6 (HSD0_M), U2.30 (USBDM_UP)
/USB2-HUB/USBH_P: U1.7 (HSD0_P), U2.31 (USBDP_UP)
/USB2-HUB/VBUS_OUT: C12.1, C13.1, C14.1, C15.1, C16.1, J2.A4 (VBUS), J2.A9 (VBUS), J2.B4 (VBUS), J2.B9 (VBUS), J17.A4 (VBUS), J17.A9 (VBUS), J17.B4 (VBUS), J17.B9 (VBUS), R10.2, R12.2, R25.2, R26.2, U4.6 (OUT)
/USB2-HUB/nOCS1: U2.13 (OCS_N1), U2.17 (OCS_N2), U2.19 (OCS_N3), U2.21 (OCS_N4), U4.4 (nFault)
/VBUS: J1.A4 (VBUS), J1.A9 (VBUS), J1.B4 (VBUS), J1.B9 (VBUS), J13.2, JP2.1 (A)
/nEXTRST: Module1.100 (nEXTRST), U2.26 (RESET_N)
GND: C1.2, C2.2, C3.2, C4.2, C5.2, C6.2, C7.2, C8.2, C9.2, C10.2, C11.2, C12.2, C13.2, C14.2, C15.2, C16.2, C17.2, C20.1, C21.1, C22.1, C23.2, C24.2, C25.2, C26.2, C27.2, C28.2, C29.2, C30.2, C31.2, C34.2, C35.2, C36.2, C37.2, IC1.4 (~OE), IC1.5 (GND), IC2.B3 (GND), J1.A1 (GND), J1.A12 (GND), J1.B1 (GND), J1.B12 (GND), J2.A1 (GND), J2.A12 (GND), J2.B1 (GND), J2.B12 (GND), J4.2, J5.9 (GND_9), J5.12 (GND_12), J5.15 (GND_15), J5.18 (GND_18), J5.21 (GND_21), J5.24 (GND_24), J8.2, J10.6, J10.9, J10.14, J10.20, J10.25, J10.30, J10.34, J10.39, J16.6 (VSS), J16.11 (SHIELD), J17.A1 (GND), J17.A12 (GND), J17.B1 (GND), J17.B12 (GND), JP7.1 (A), JP8.3 (B), Module1.1 (GND), Module1.2 (GND), Module1.7 (GND), Module1.8 (GND), Module1.13 (GND), Module1.14 (GND), Module1.22 (GND), Module1.23 (GND), Module1.32 (GND), Module1.33 (GND), Module1.42 (GND), Module1.43 (GND), Module1.52 (GND), Module1.53 (GND), Module1.59 (GND), Module1.60 (GND), Module1.65 (GND), Module1.66 (GND), Module1.71 (GND), Module1.74 (GND), Module1.98 (GND), Module1.107 (GND), Module1.108 (GND), Module1.113 (GND), Module1.114 (GND), Module1.119 (GND), Module1.120 (GND), Module1.125 (GND), Module1.126 (GND), Module1.131 (GND), Module1.132 (GND), Module1.137 (GND), Module1.138 (GND), Module1.144 (GND), Module1.150 (GND), Module1.155 (GND), Module1.156 (GND), Module1.161 (GND), Module1.162 (GND), Module1.167 (GND), Module1.168 (GND), Module1.173 (GND), Module1.174 (GND), Module1.179 (GND), Module1.180 (GND), Module1.185 (GND), Module1.186 (GND), Module1.191 (GND), Module1.192 (GND), Module1.197 (GND), Module1.198 (GND), R1.2, R3.2, R4.2, R5.2, R6.1, R7.2, R8.1, R9.1, R11.2, S1.2, S3.2, S4.2, S5.2, S6.1, SW1.2, U1.5 (GND), U1.10 (nOE), U2.37 (VSS), U3.3 (GND), U3.8 (GND), U4.2 (GND), U5.5 (GND), U5.6 (GND), U5.7 (GND), U5.8 (GND), U5.9 (GND), U5.10 (GND), U5.11 (GND), U5.12 (GND), U5.13 (GND), U7.2 (GND), U9.3 (GND), U10.2 (GND), U13.3 (GND), U13.8 (GND)
unnamed: D1.1 (K), R16.1
unnamed: D2.1 (K), R19.1
unnamed: D5.2 (A), IC2.A3 (SW), L2.2
unnamed: C36.1, C37.1, D5.1 (K), IC2.D1 (OVP), JP6.1 (A)
unnamed: IC2.B1 (HWEN), JP8.2 (C)
unnamed: C35.1, IC2.C3 (IN), JP5.2 (B), L2.1
unnamed: IC2.C2 (SEL), JP7.2 (C)
unnamed: J1.A5 (CC1), R9.2
unnamed: J1.B5 (CC2), R8.2
unnamed: J2.A5 (CC1), R10.1
unnamed: J2.B5 (CC2), R12.1
unnamed: C17.1, J4.1, U5.14 (VBAT)
unnamed: J16.10 (DET_A), R20.2
unnamed: J16.9 (DET_B), R21.2
unnamed: J17.A5 (CC1), R25.1
unnamed: J17.B5 (CC2), R26.1
unnamed: R19.2, U9.4
unnamed: R7.1, U2.25 (HS_IND/CFG_SEL1)
unnamed: R6.2, U2.35 (RBIAS)
unnamed: R3.1, U2.24 (SCL/SMBCLK/CFG_SEL0)
unnamed: R4.1, U2.22 (SDA/SMBDATA/NON_REM1)
unnamed: R5.1, U2.28 (SUSP_IND/LOCAL_PWR/NON_REM0)
unnamed: U2.33 (XTALIN/CLKIN), Y1.3 (XTAL_2)
unnamed: U2.32 (XTALOUT), Y1.1 (XTAL_1)
unnamed: U3.1 (D1+), U3.10
unnamed: U3.2 (D1-), U3.9
unnamed: R11.1, U4.5 (ILIM)
unnamed: U13.1 (D1+), U13.10
unnamed: U13.2 (D1-), U13.9
unnamed: C2.1, Y1.2 (GND_1)
unnamed: C1.1, Y1.4 (GND_2)

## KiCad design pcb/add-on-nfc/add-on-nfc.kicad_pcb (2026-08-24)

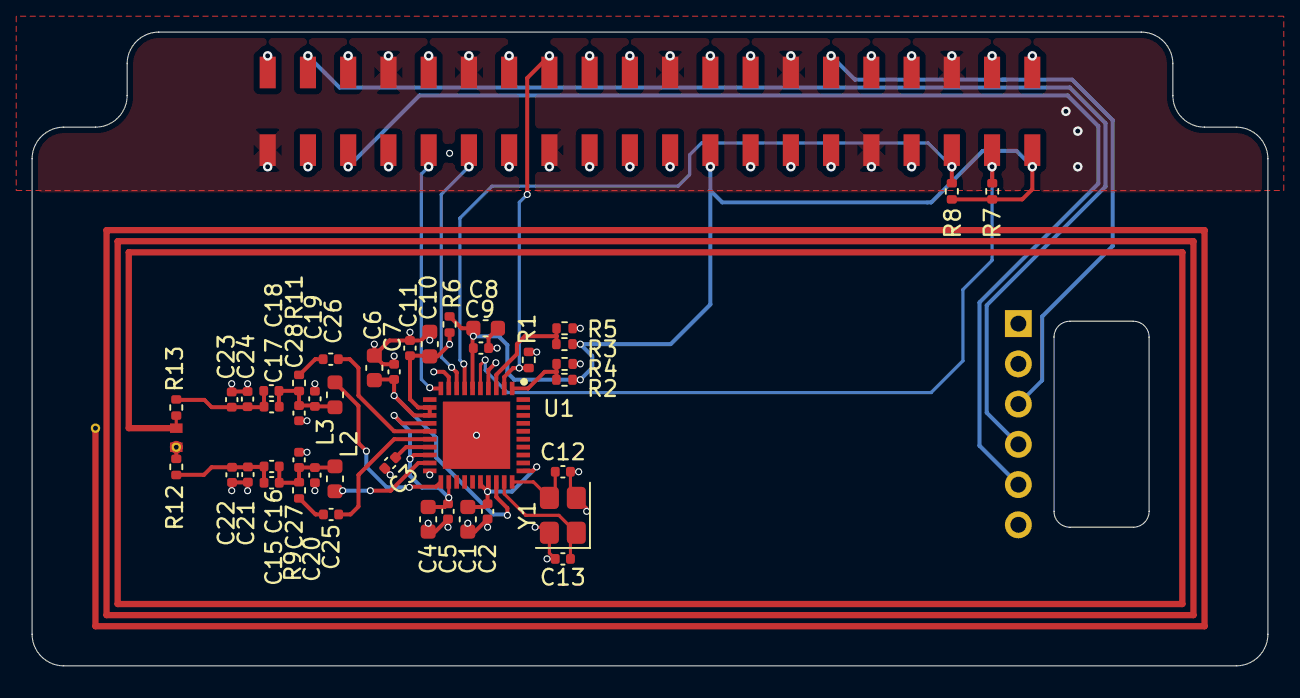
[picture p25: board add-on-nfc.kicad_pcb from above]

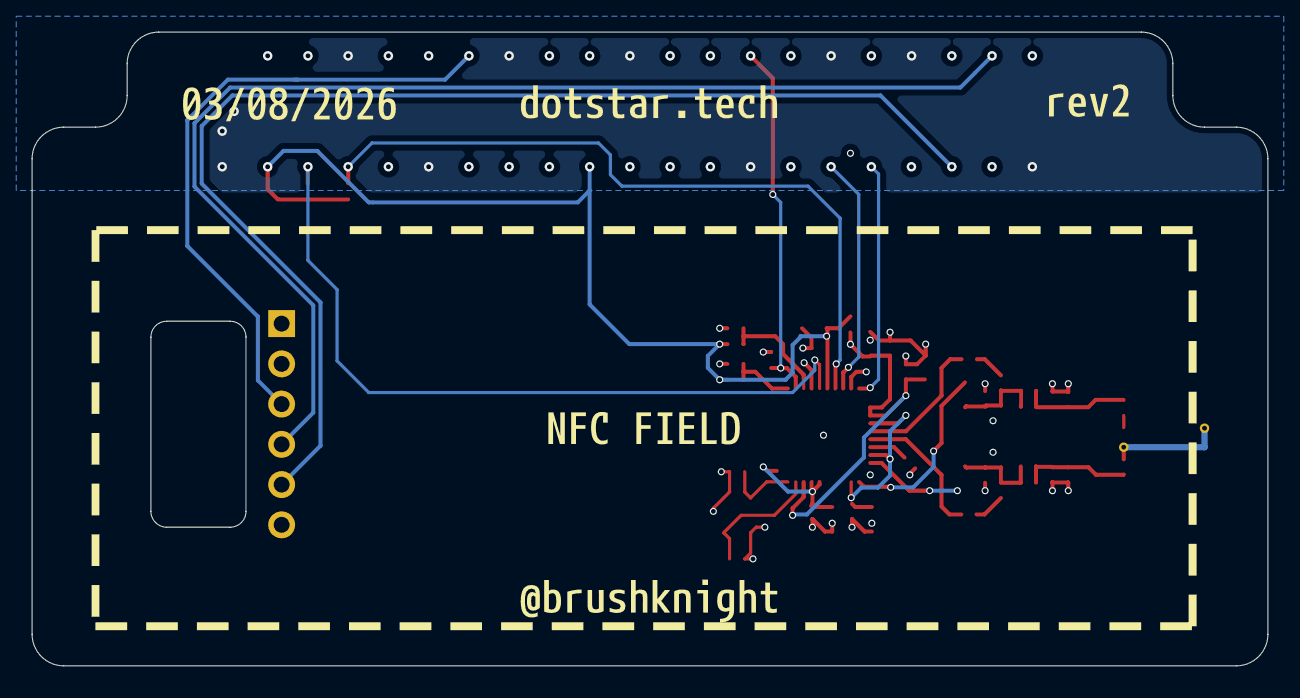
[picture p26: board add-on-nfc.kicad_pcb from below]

Board: 4 copper layers, 78.0 x 40.0 mm, 51 parts (5 on the bottom side), 30 nets.

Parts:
AE1: NFC_ANT_70x25_N3
C1, C4, C6, C8, C10: 10uF; C_0603_1608Metric
C2, C3, C5, C7, C9, C11: 100nF; C_0402_1005Metric
C12, C13: 15pF; C_0402_1005Metric
C15, C18: NC; C_0402_1005Metric
C16, C17: 82pF; C_0402_1005Metric
C19, C20: 270pF; C_0402_1005Metric
C21, C24: 150pF; C_0402_1005Metric
C22, C23: 68pF; C_0402_1005Metric
C25, C26: 1nF; C_0402_1005Metric
C27, C28: 56pF; C_0402_1005Metric
J5: Mic Adafruit; SPH0645LM4H
J10: PZ254-2-20-WS; PM254-2-20-WS-8.5
L2, L3: 160nH; L_0603_1608Metric
R1: 10K; R_0402_1005Metric
R2, R3: 10K/NC; R_0402_1005Metric
R4, R5: 100K; R_0402_1005Metric
R6: 0; R_0402_1005Metric
R7, R8: 4.7K/NC; R_0402_1005Metric
R9, R11: 2.2K; R_0402_1005Metric
R12, R13: 1.3K; R_0402_1005Metric
U1: PN7160A1HN_C100E; QFN50P600X600X100-41N-D
Y1: Crystal_GND24; Crystal_SMD_3225-4Pin_3.2x2.5mm
kibuzzard-6A72FB9B: G***; kibuzzard-6A72FB9B
kibuzzard-6A7047E1: G***; kibuzzard-6A7047E1
kibuzzard-6A7047FA: G***; kibuzzard-6A7047FA
kibuzzard-6A70481C: G***; kibuzzard-6A70481C
kibuzzard-6A70487D: G***; kibuzzard-6A70487D

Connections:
+3.3V: C8.1, C9.1, J5.1, J10.23, J10.39, R2.1, R3.1, R6.1, R7.2, R8.2, U1.6 (VDD_1)
+5V: C6.1, C7.1, C10.1, C11.1, J10.38, J10.40, R6.2, U1.12 (VBAT2), U1.13 (VDD(UP)), U1.28 (VBAT)
/ADDR0/NSS: R2.2, R4.2, U1.1 (I2C_ADR0/SPI_NSS)
/ADDR1/MOSI: R3.2, R5.2, U1.3 (I2C_ADR1/SPI_MOSI)
/DWL_REQ: J10.16, R1.2, U1.2 (DWL_REQ)
/GPIO2: J10.37, R7.1, U1.5 (I2C_SDA/SPI_MISO)
/GPIO3: J10.35, R8.1, U1.7 (I2C_SCL/SPI_SCK)
/GPIO5: J10.11, U1.8 (IRQ)
/GPIO6: J10.9, U1.10 (VEN)
/GPIO18: J5.3, J10.30
/GPIO19: J5.5, J10.5
/GPIO20: J5.4, J10.4
/RXN: C26.1, U1.15 (RXN)
/RXP: C25.1, U1.16 (RXP)
/TX1: L3.1, U1.21 (TX1)
/TX2: L2.1, U1.19 (TX2)
GND: C1.2, C2.2, C3.2, C4.2, C5.2, C6.2, C7.2, C8.2, C9.2, C10.2, C11.2, C12.2, C13.2, C19.2, C20.1, C21.1, C22.1, C23.2, C24.2, C27.1, C28.2, J5.2, J10.1, J10.8, J10.12, J10.15, J10.22, J10.28, J10.31, J10.36, R1.1, R4.1, R5.1, U1.4 (VSS_1), U1.9 (VSS(A)), U1.20 (VSS(TX)), U1.41 (VSS_2), Y1.2 (G), Y1.4 (G)
unnamed: AE1.1 (ANT+), R12.2
unnamed: AE1.2 (ANT-), R13.2
unnamed: C15.1, C16.1, C20.2, C27.2, L2.2, R9.1
unnamed: C15.2, C16.2, C21.2, C22.2, R12.1
unnamed: C17.1, C18.1, C19.1, C28.1, L3.2, R11.2
unnamed: C17.2, C18.2, C23.1, C24.1, R13.1
unnamed: C25.2, R9.2
unnamed: C26.2, R11.1
unnamed: C12.1, U1.30 (NFC_CLK_XTAL1), Y1.3
unnamed: C4.1, C5.1, U1.14 (VDD(TX)), U1.18 (TVDD_IN), U1.22 (VDD_IN2)
unnamed: C1.1, C2.1, U1.26 (VDD(A)), U1.27 (VDD_2), U1.31 (VDD(D))
unnamed: C3.1, U1.17 (VDD(VMID))
unnamed: C13.1, U1.29 (XTAL2), Y1.1

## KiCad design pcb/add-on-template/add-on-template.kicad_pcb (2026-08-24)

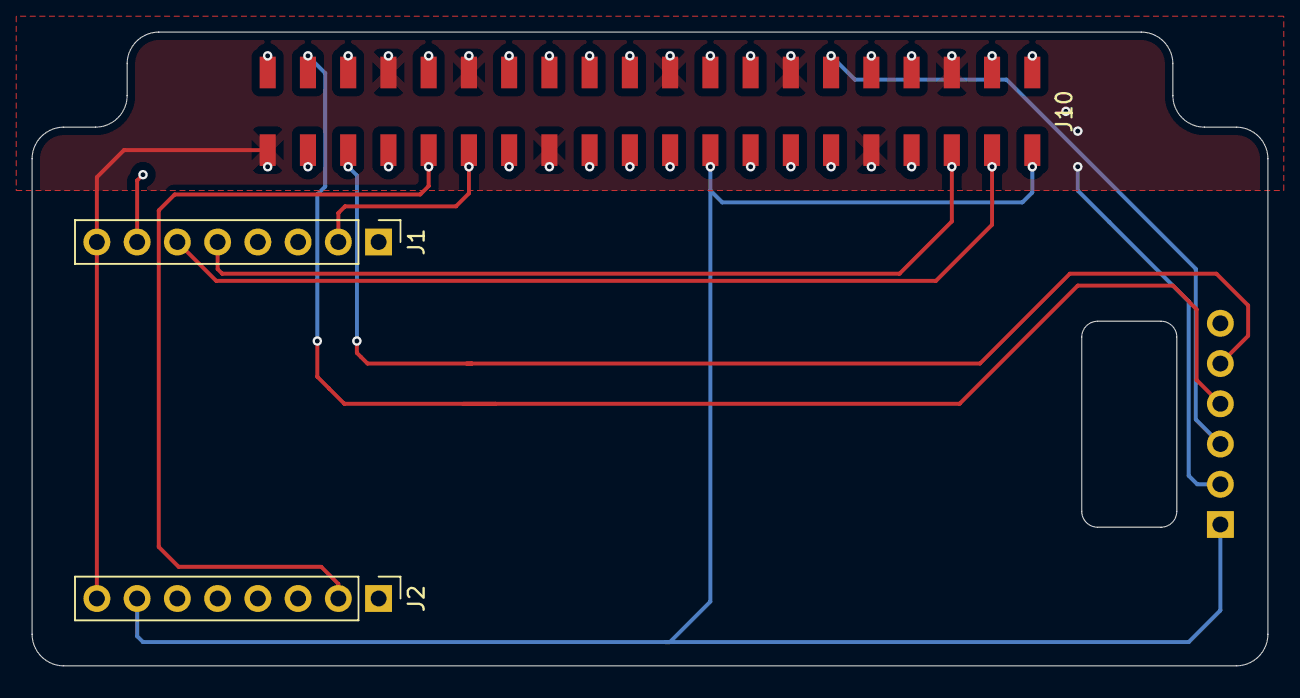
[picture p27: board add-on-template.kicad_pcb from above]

Board: 4 copper layers, 78.0 x 40.0 mm, 4 parts (0 on the bottom side), 10 nets.

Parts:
J1: Left, i2c; PinHeader_1x08_P2.54mm_Vertical
J2: Right, 3v; PinHeader_1x08_P2.54mm_Vertical
J5: Mic Adafruit; SPH0645LM4H
J10: PZ254-2-20-WS; PM254-2-20-WS-8.5

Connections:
+3.3V: J2.7, J5.1, J10.23, J10.39
+5V: J1.7, J10.38, J10.40
/GPIO2: J1.6, J10.37
/GPIO3: J1.5, J10.35
/GPIO5: J1.2, J10.11
/GPIO6: J2.2, J10.9
/GPIO18: J5.3, J10.30
/GPIO19: J5.5, J10.5
/GPIO20: J5.4, J10.4
GND: J1.8, J2.8, J5.2, J10.1, J10.8, J10.12, J10.15, J10.22, J10.28, J10.31, J10.36

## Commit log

2026-01-09 wall panel v0.2
    [CM4_GPIO.kicad_sch, CM4_HighSpeed.kicad_sch, PCIe.kicad_sch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]
2026-01-09 added cad files
    [back_button.step, back_lid.step, frame.step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]
2026-02-05 wall panel v0.3
    [CM4_GPIO.kicad_sch, CM4_HighSpeed.kicad_sch, RTC.kicad_sch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]
2026-02-06 added poe backplate v0.2
    [poe-backplate.kicad_pcb, poe-backplate.kicad_sch, poe.kicad_sch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]
2026-08-24 small fixes of v0.3.1
    [CM4_GPIO.kicad_sch, CM4_HighSpeed.kicad_sch, RTC.kicad_sch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]
2026-08-24 pogo pins wall panel
    [CM4_GPIO.kicad_sch, CM4_HighSpeed.kicad_sch, RTC.kicad_sch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]
2026-08-24 Custom NFC board - rev2
    [add-on-nfc.kicad_pcb, add-on-nfc.kicad_sch]
2026-08-24 PoE backplate
    [poe-backplate.kicad_pcb, poe-backplate.kicad_sch, poe.kicad_sch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]
2026-08-24 NFC antenna tuning
    [nfc-tuning.kicad_pcb, nfc-tuning.kicad_sch]
2026-08-24 wall panel rev 5
    [CM4_GPIO.kicad_sch, CM4_HighSpeed.kicad_sch, RTC.kicad_sch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]

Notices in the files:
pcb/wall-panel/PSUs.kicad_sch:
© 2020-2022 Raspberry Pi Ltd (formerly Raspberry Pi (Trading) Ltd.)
